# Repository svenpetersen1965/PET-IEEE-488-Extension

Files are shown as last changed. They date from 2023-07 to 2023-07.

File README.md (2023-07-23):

# PET-IEEE-488-Extension
This is a splitter and cable adapter for the Commodore PET IEEE-488 edge connector port. It can serve for connecting a "cheap" standard IEEE-488 cable with both sides IEEE-488 connectors to the edge connector IEEE-488 port of the PET. The original cables with an edge connector are a fortune nowadays.

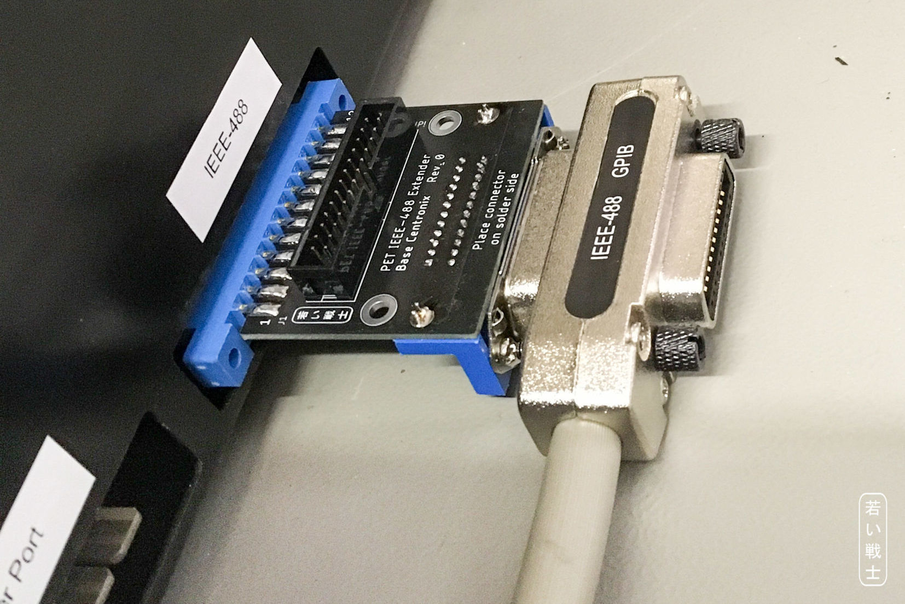
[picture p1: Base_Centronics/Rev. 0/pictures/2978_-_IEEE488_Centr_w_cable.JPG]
Centronics Base


Also, it can serve as a splitter for the SD2PET future. 

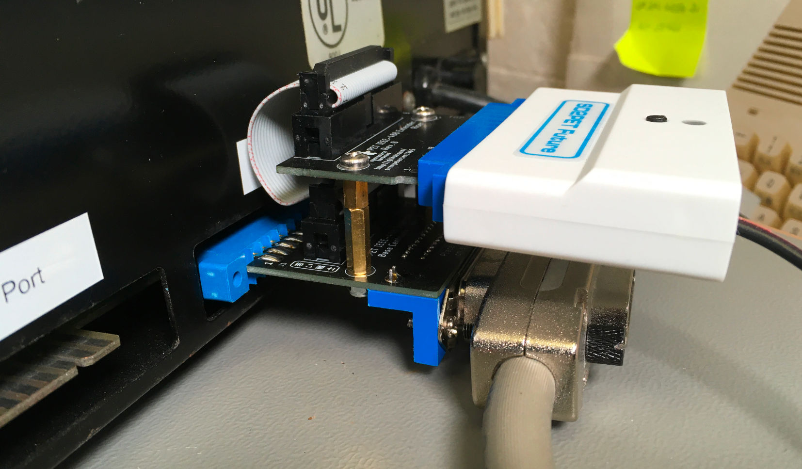
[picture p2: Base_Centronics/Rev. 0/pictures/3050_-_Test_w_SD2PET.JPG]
with Riser board and SD2PET future


There is a 3D printed case with label for the adapter. 

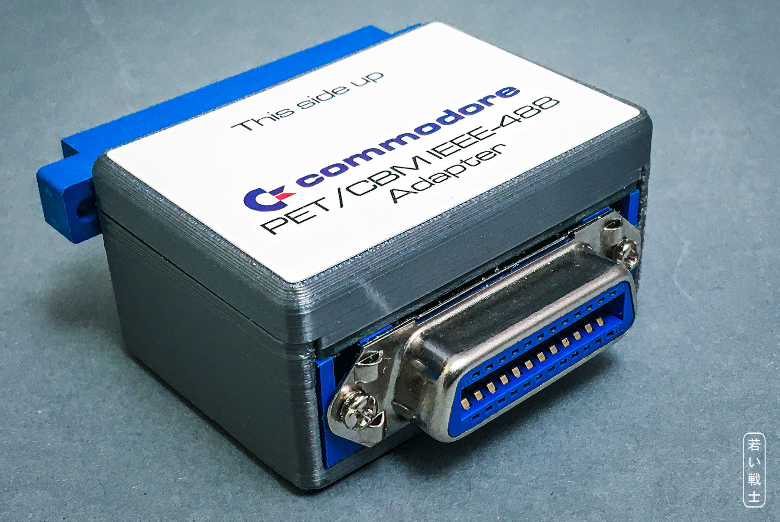
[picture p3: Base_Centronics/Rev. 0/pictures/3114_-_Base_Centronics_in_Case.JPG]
with Case


For splitting the bus, there is a riser card, which attaches to both, the normal and the centronics base board.

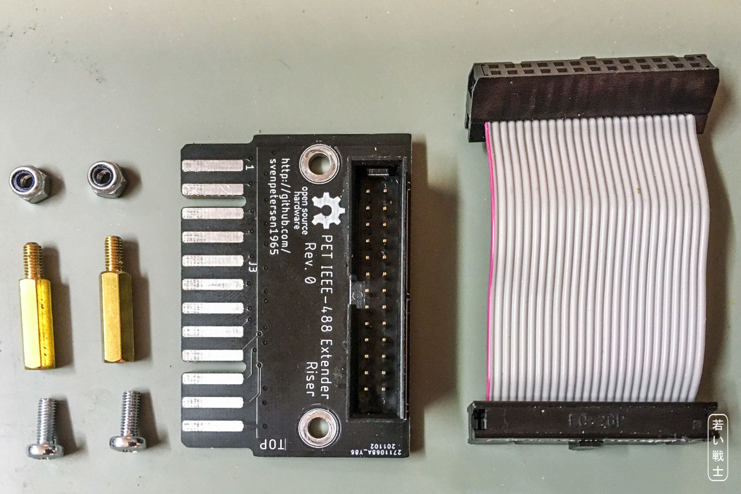
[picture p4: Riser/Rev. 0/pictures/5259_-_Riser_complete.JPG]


Here is a close up of the configuration with the riser card and the SD2PET.

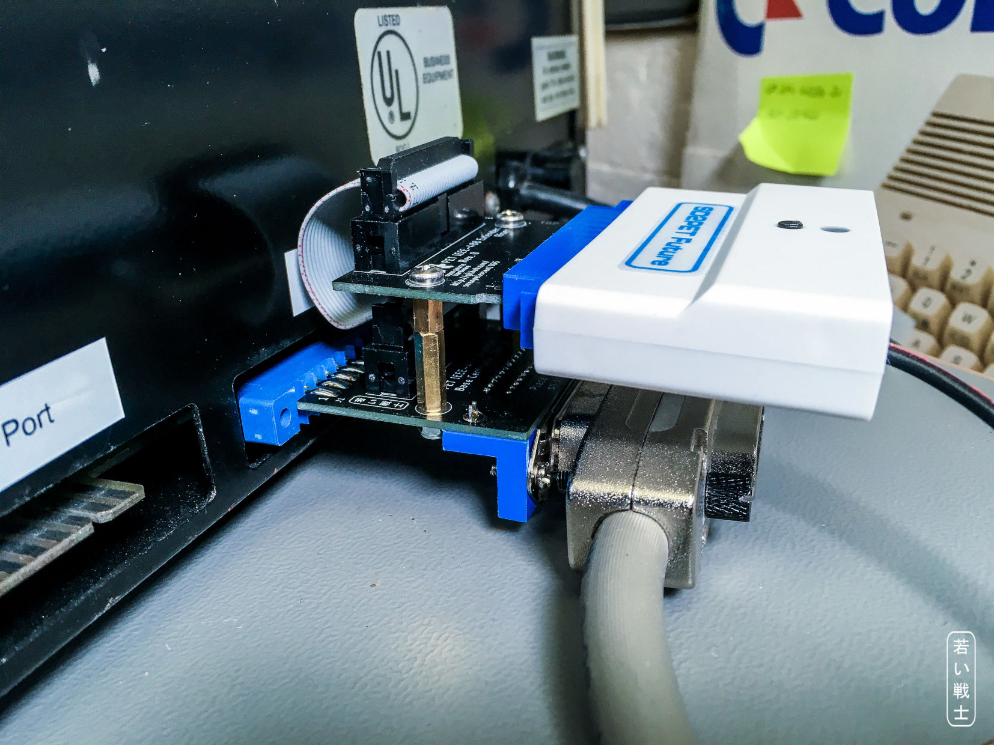
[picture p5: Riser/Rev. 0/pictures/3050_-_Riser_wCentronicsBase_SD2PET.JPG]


In this configuration, only the bottom part of the case is installed.

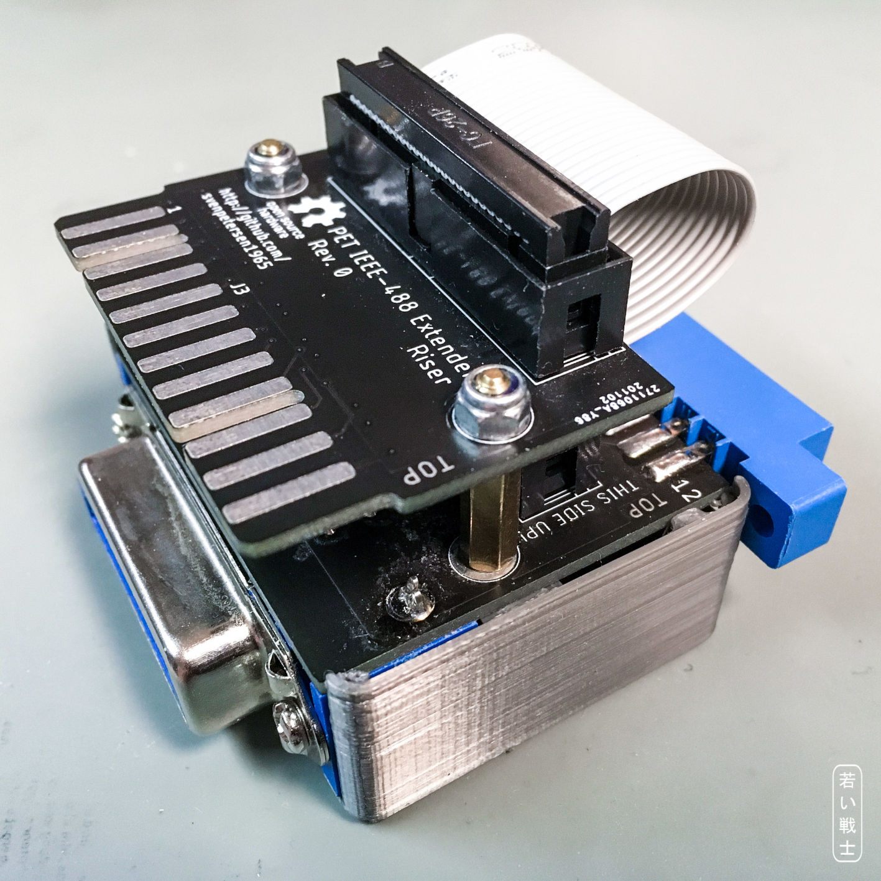
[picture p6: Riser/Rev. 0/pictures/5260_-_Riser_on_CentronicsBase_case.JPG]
with Case


This is the base board with an edge connector:

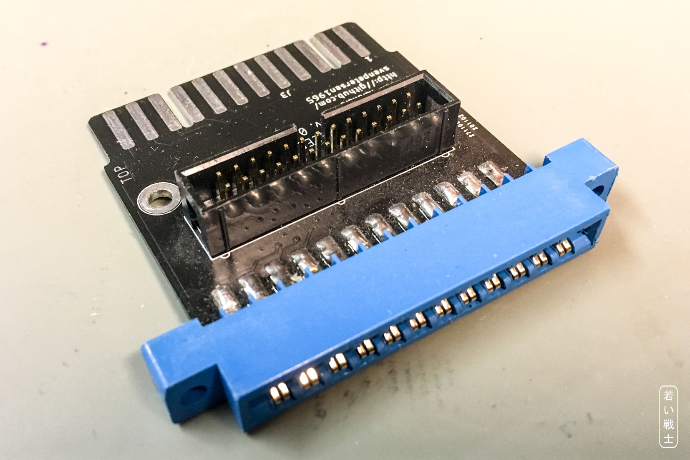
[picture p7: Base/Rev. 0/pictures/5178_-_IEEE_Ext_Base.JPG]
base with edge connector


Serving as an easy adapter for a DIY ribbon cable.

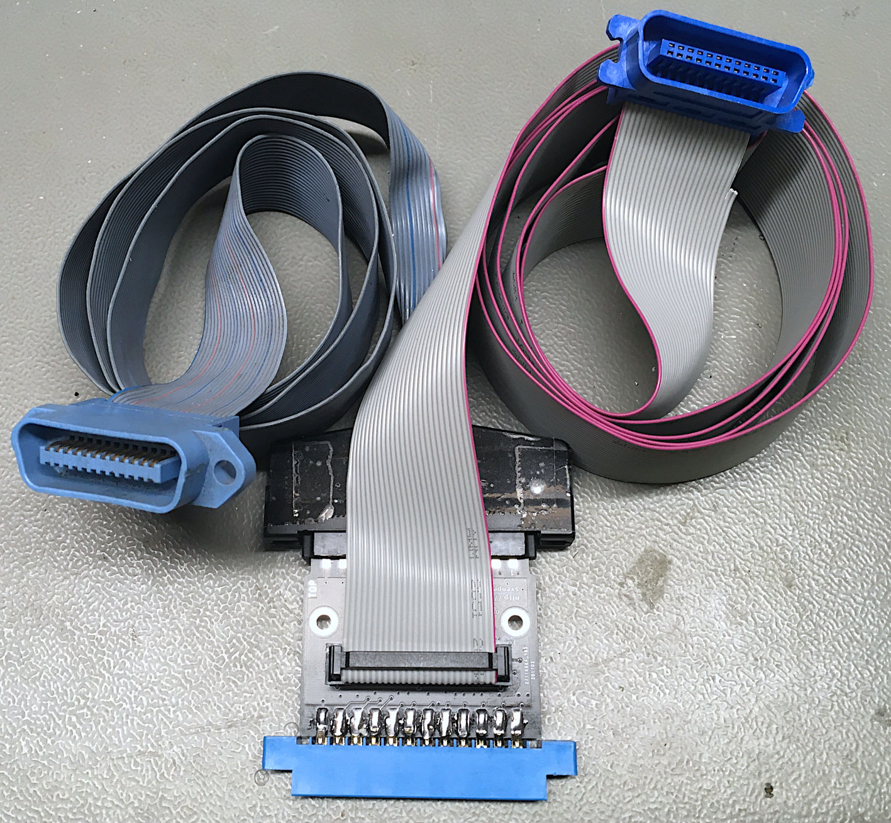
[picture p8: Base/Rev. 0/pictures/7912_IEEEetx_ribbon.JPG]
base with edge connector


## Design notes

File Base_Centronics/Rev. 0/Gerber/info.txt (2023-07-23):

      
       Board: IEEE_EXT_Base_Centr
       Rev.:  0
  
       Files:
       ======
  
       All Gerber files are generated in extended gerber format (RS274X)
       *.TOP        : Film top copper
       *.BOT        :  -"- bottom copper
       *.STC        :  -"- top soldermask 
       *.STS        :  -"- bottom soldermask
       *.PLC        :  -"- silk screen top
       *.PLS        :  -"- silk screen bottom
       *.DK         : Drills plated Through (Excellon)
       *.NDK        : Drills not plated Through (Excellon)
       *.OUT        : Board outline

       Board Size:
       ===========
       Length     :   54.0 mm
       Width      :   44.0 mm
       Thickness  :   1.6 mm
       Material   :   FR 4
       Copper     :   35 um
       Surface    :   HASL
       
       Remarks:
       ========
       Width >= 8mil
       Distance >= 6mil
       Drill >= 0.35mm

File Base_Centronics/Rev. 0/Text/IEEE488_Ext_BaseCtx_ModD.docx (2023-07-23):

Commodore PET IEEE-488 Extender Base Centronics Rev. 0

Module Description

The IEEE-488 extender can serve multiple purposes:

1. Splitting the card edge IEEE-488 connector via a riser board (Project No. 170), so an additional device like a SD2PET future can be connected.
2. Adapting an IEEE-488 cable to the edge connector of the PET.

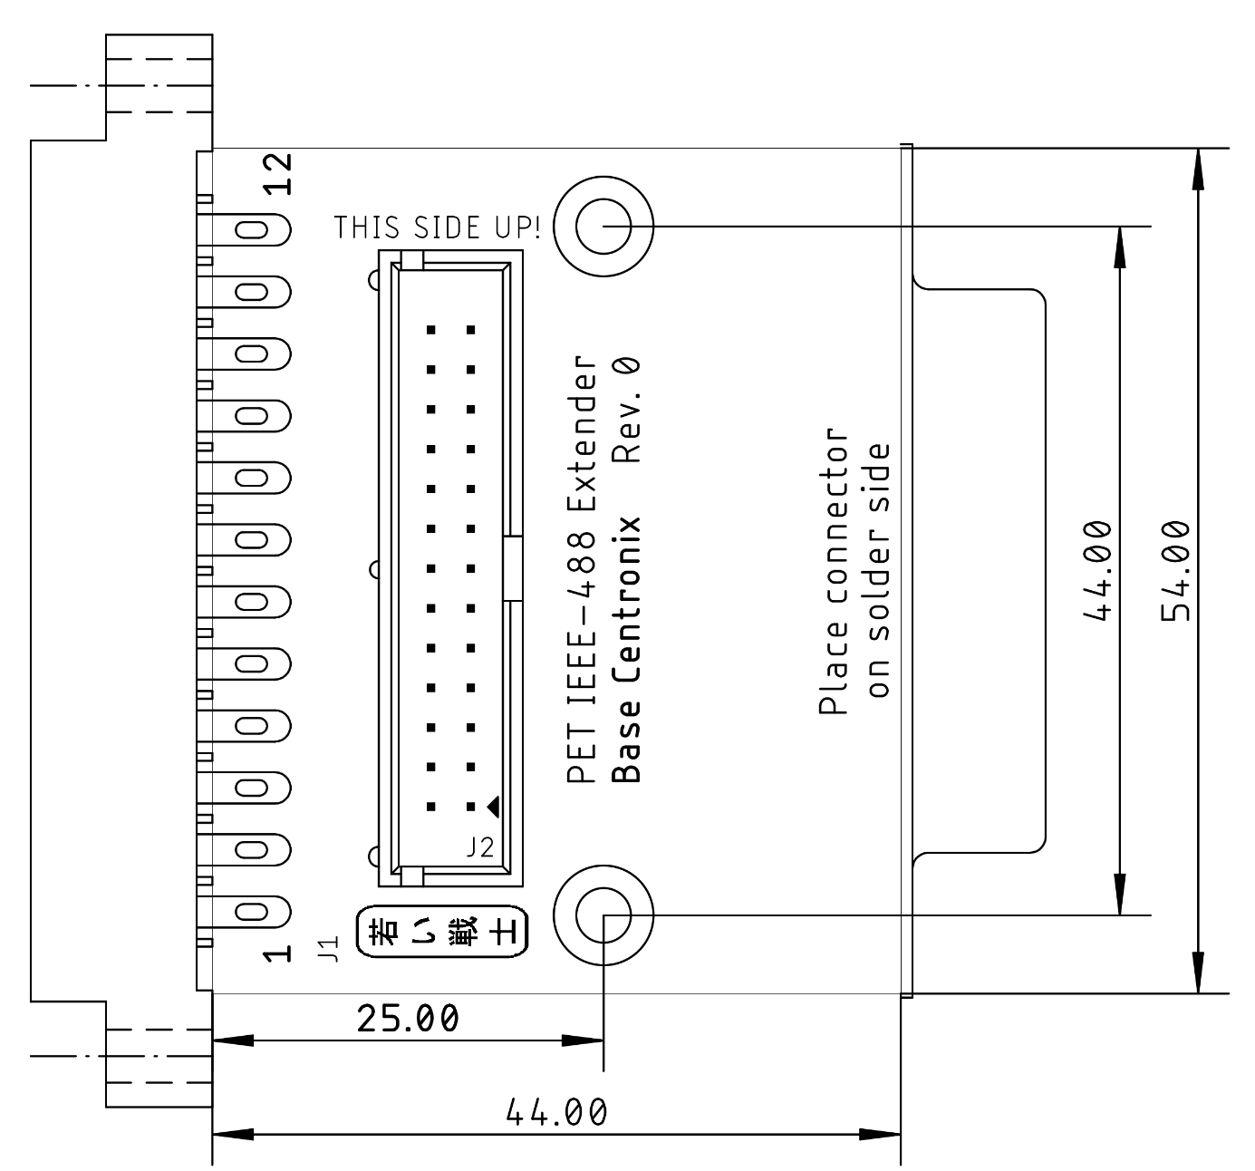
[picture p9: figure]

Figure 1: Dimensions of the IEEE-488 Extender

# 3D-Printed Case

Depending on the intended usage, there are different sorts of 3D cases/configurations. The 3D-printed case provides a good support for the extension board and the cable. If it is only intended to use the extension as an adapter for the Centronics type (=standard) IEEE-488 cables, the top shell can be installed (J2 cannot be assembled in this case). The height above the desktop of the PET is different than that of the Tynemouth Software/TFW8bit miniPET. The miniPET adapter case is 2mm higher.

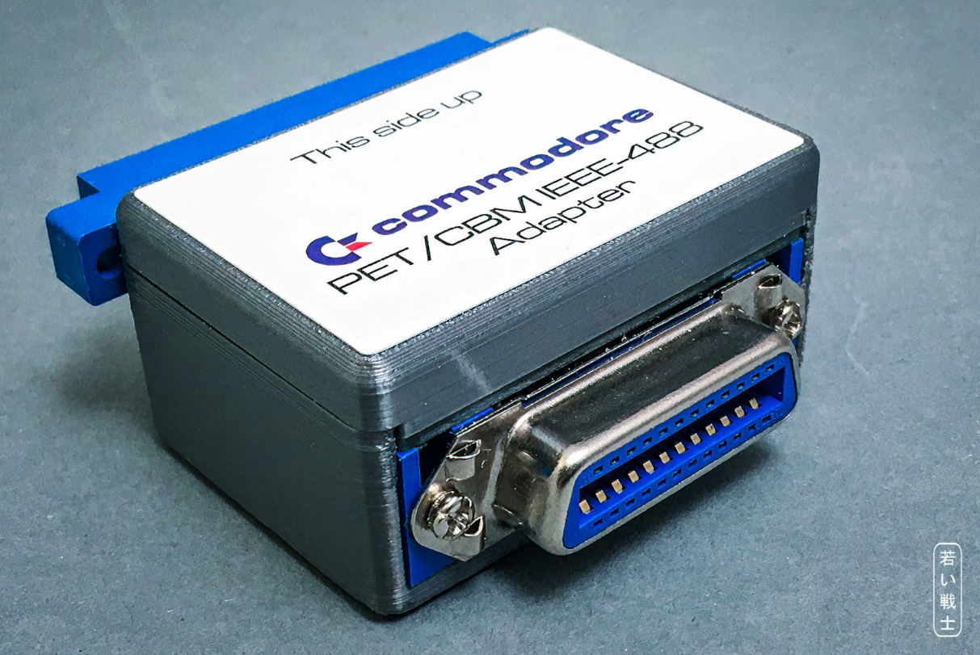
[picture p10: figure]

Figure 2: Full 3D printed case

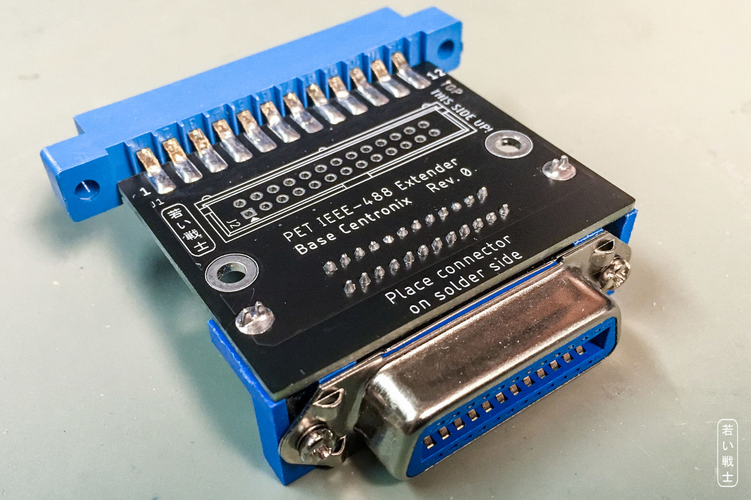
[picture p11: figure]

Figure 3: Centronics Base without J2

Figure 3 shows the Centronics Base without J2 to allow the top shell of the case to be installed.


Figure 4: Centronics Base with Riser and the bottom shell installed only

# Connectors

J1 is a female card edge connector, that connects to the PET/CBM Mainboard, J3 is a 24p. female Centronics connector (fits IEEE-488) (Ali Express “Series 57”), which connects to the IEEE-488 peripherals via an IEEE-488 cable. J2 is a 2x13 pin header/box connector.

J1 | J3 | Signal | J2 | J2 | Signal | J3 | J1
1 | 1 | DIO1 | 1 | 2 | DIO5 | 13 | A
2 | 2 | DIO2 | 3 | 4 | DIO6 | 14 | B
3 | 3 | DIO3 | 5 | 6 | DIO7 | 15 | C
4 | 4 | DIO4 | 7 | 8 | DIO8 | 16 | D
5 | 5 | EOI | 9 | 10 | REN | 17 | E
6 | 6 | DAV | 11 | 12 | GND | 18 | F
7 | 7 | NRFD | 13 | 14 | GND | 19 | H
8 | 8 | NDAC | 15 | 16 | GND | 20 | J
9 | 9 | IFC | 17 | 18 | GND | 21 | K
10 | 10 | SRQ | 19 | 20 | GND | 22 | L
11 | 11 | ATN | 21 | 22 | GND | 23 | M
12 | 12 | GND | 23 | 24 | GND | 24 | N
- | - | GND | 25 | 26 | GND | - | -

Table 1: IEEE-488 signal pinouts

The shield of J3 is connected to GND.

# SD2PET future Splitter

The SD2PET future has an edge connector IEEE-488 interface, which does not allow to connect any other IEEE-488 peripheral. It might be desired to do so, though. In this case, the SD2PET future has to drive both, the PET and the peripheral bus load. The maximum load is not defined.

The configuration was tested with a CBM8032 and a CBM8050 floppy disk drive attached via a 1.5 meter long IEEE-488 cable. The CBM8050 has to be set (via hardware) to a device address other than 8, since this is the default address of the SD2PET future. It is not possible to switch off the CBM8050 and reconfigure the device address of the SD2PET.

Using the SD2PET future and a printer was not tested, but very likely works, since the interface circuitry is similar to the CBM8050.

The bus splitting requires the riser board, like shown in Figure 4.

# Revision History

## Rev. 0

- Prototype (fully functional)

IEEE488_Ext_BaseCtx_ModD.docx 23.07.2023 17:27 Drafted by Sven Petersen Page 2 of 2 Doc.-No.: 204-6-01-00

IEEE488_Ext_BaseCtx_ModD.docx 23.07.2023 17:27 Drafted by Sven Petersen Page 1 of 1 Doc.-No.: 000-6-00-00

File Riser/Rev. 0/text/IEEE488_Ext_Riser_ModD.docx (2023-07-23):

Commodore PET IEEE-488 Extender – Riser Board Rev. 0

Module Description

# Introduction

The IEEE-488 extender riser board is connected to either the base board with edge connector (Project 169) or the base board with Centronics connector (24p. = IEEE-488 connector, Project. No. 204). It serves for connecting IEEE cables with and edge connector or a peripheral like the SD2PET, which has an edge connector installed.

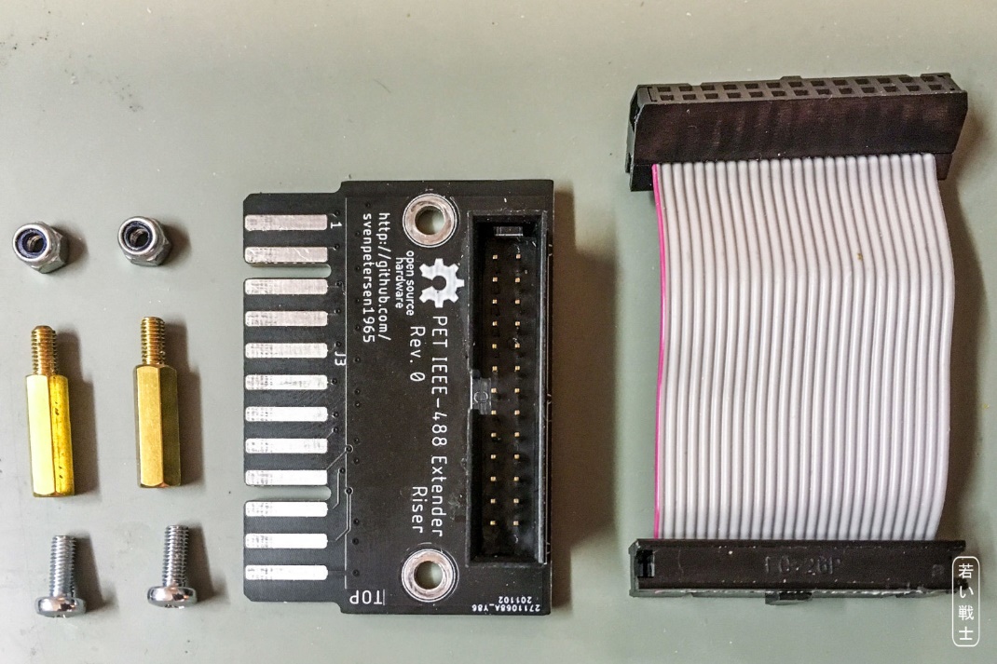
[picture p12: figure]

Figure 1: Riser Board with jumper cable and mounting material

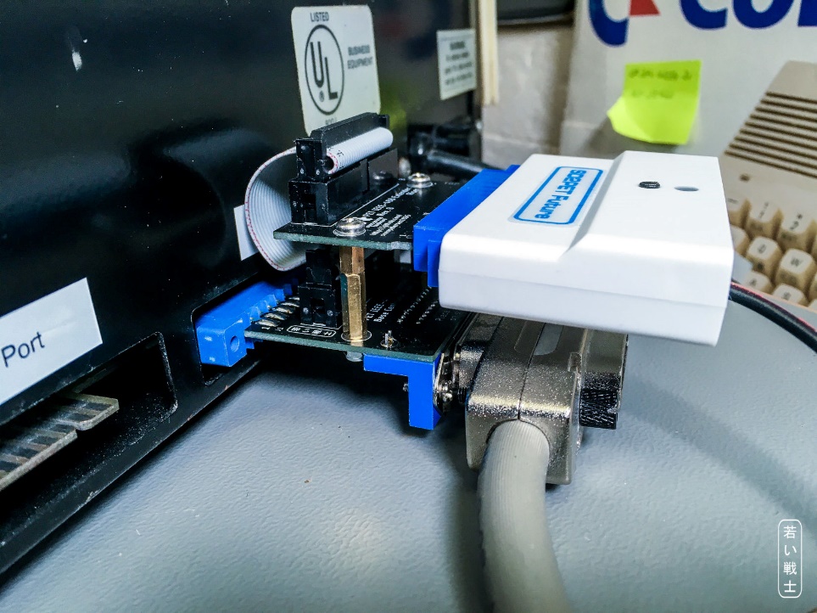
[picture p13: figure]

Figure 2: Riser Board on a Centronics Base Board with an SD2PET

# Dimensions

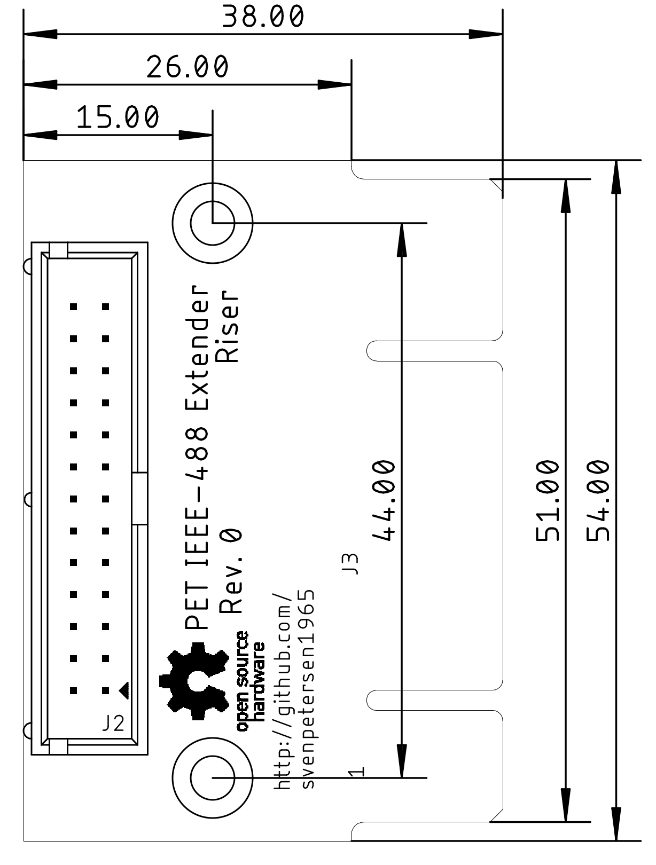
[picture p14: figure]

Figure 3: Dimensions of the IEEE-488 Extender

# Connectors

J3/top | Signal | J2 | J2 | Signal | J3/bottom
1 | DIO1 | 1 | 2 | DIO5 | A
2 | DIO2 | 3 | 4 | DIO6 | B
3 | DIO3 | 5 | 6 | DIO7 | C
4 | DIO4 | 7 | 8 | DIO8 | D
5 | EOI | 9 | 10 | REN | E
6 | DAV | 11 | 12 | GND | F
7 | NRFD | 13 | 14 | GND | H
8 | NDAC | 15 | 16 | GND | J
9 | IFC | 17 | 18 | GND | K
10 | SRQ | 19 | 20 | GND | L
11 | ATN | 21 | 22 | GND | M
12 | GND | 23 | 24 | GND | N
- | GND | 25 | 26 | GND | -

Table 1: IEEE-488 signal pinouts

J3 is a card edge structure on the PCB, which connects to the IEEE-488 peripherals via the PET-IEEE-488 cable or directly (in case of the SD2PET future). J2 is a 2x13 pin header/box connector for the jumper cable to the respective base board.

# Cable

The jumper ribbon cable connects J2 or the Riser Board to J2 of the desired base board. Since this cable is usually installed only once, there is no need for a strain relief. This way, the standoff between riser board and the base board can be 15mm only.

# 3D-Printed Case

The bottom Shell of the Case for the Centronics Base can be used to support the board stack.


Figure 4: Board stack with Centronics Base and the bottom shell of the Centronics case

The recommended mounting material:

- 2x 15mm standoffs
- 2x M3x8 Screws (e.g. DIN 7985, Philips dead)
- 2x Nut M3 self-locking (DIN 985)

# Application Note

When using it as a splitter for the SD2PET, it is not tested to drive more than the SD2PET and one more peripheral. It is suspected, that the SD2PET is not capable to drive bussed with several devices.

# Revision History

## Rev. 0

- Prototype (fully functional)

IEEE488_Ext_Riser_ModD.docx 18.06.2023 22:15 Drafted by Sven Petersen Page 2 of 2 Doc.-No.: 170-6-01-00

IEEE488_Ext_Riser_ModD.docx 18.06.2023 22:15 Drafted by Sven Petersen Page 1 of 1 Doc.-No.: 000-6-00-00

ENZIANWEG 16 ● 83052 BRUCKMÜHL TEL (08062) 728704 ● FAX (08062) 728705

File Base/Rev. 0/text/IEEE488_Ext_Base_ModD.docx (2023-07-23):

Commodore PET IEEE-488 Extender Base Board Rev. 0

Module Description

The IEEE-488 extender can serve multiple purposes:

1. Splitting the card edge IEEE-488 connector, so an additional device other than a SD2PET future can be connected.
2. Connecting a cheap DIY ribbon IEEE-488 cable. It is recommended to keep this ribbon cable as short as possible

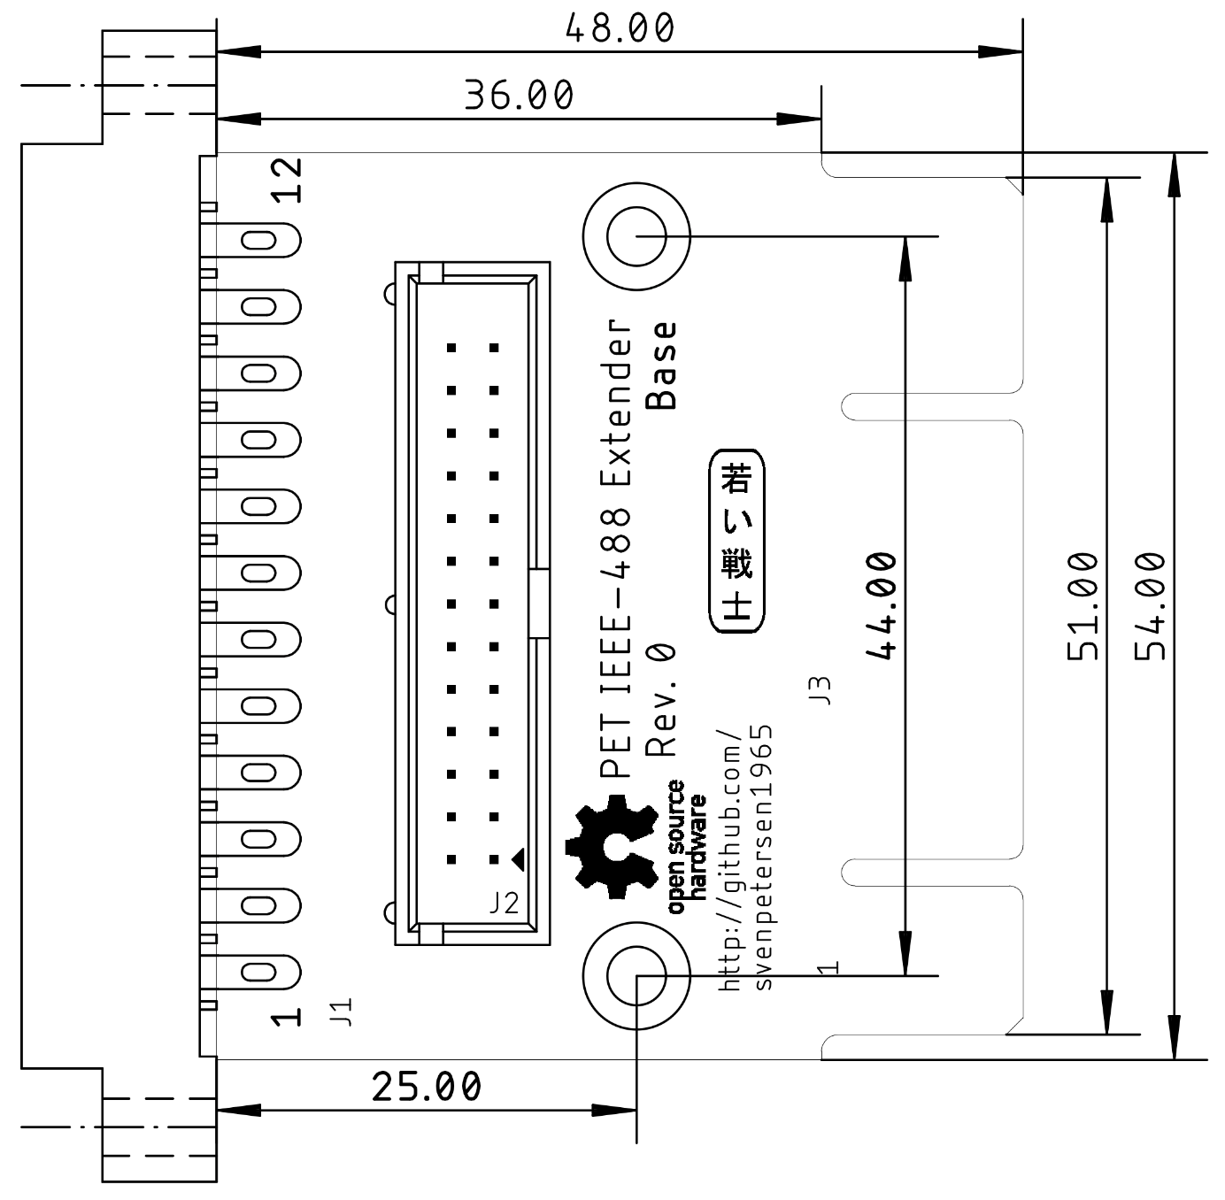
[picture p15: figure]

Figure 1: Dimensions of the IEEE-488 Extender

# Connectors

J1 is a female card edge connector, that connects to the PET/CBM Mainboard, J3 is a card edge structure on the PCB, which connects to the IEEE-488 peripherals via the PET-IEEE-488 cable or directly (in case of the SD2PET future). J2 is a 2x13 pin header/box connector.

J1, J3/top | Signal | J2 | J2 | Signal | J1, J3/bottom
1 | DIO1 | 1 | 2 | DIO5 | A
2 | DIO2 | 3 | 4 | DIO6 | B
3 | DIO3 | 5 | 6 | DIO7 | C
4 | DIO4 | 7 | 8 | DIO8 | D
5 | EOI | 9 | 10 | REN | E
6 | DAV | 11 | 12 | GND | F
7 | NRFD | 13 | 14 | GND | H
8 | NDAC | 15 | 16 | GND | J
9 | IFC | 17 | 18 | GND | K
10 | SRQ | 19 | 20 | GND | L
11 | ATN | 21 | 22 | GND | M
12 | GND | 23 | 24 | GND | N
- | GND | 25 | 26 | GND | -

Table 1: IEEE-488 signal pinouts

# Pictures

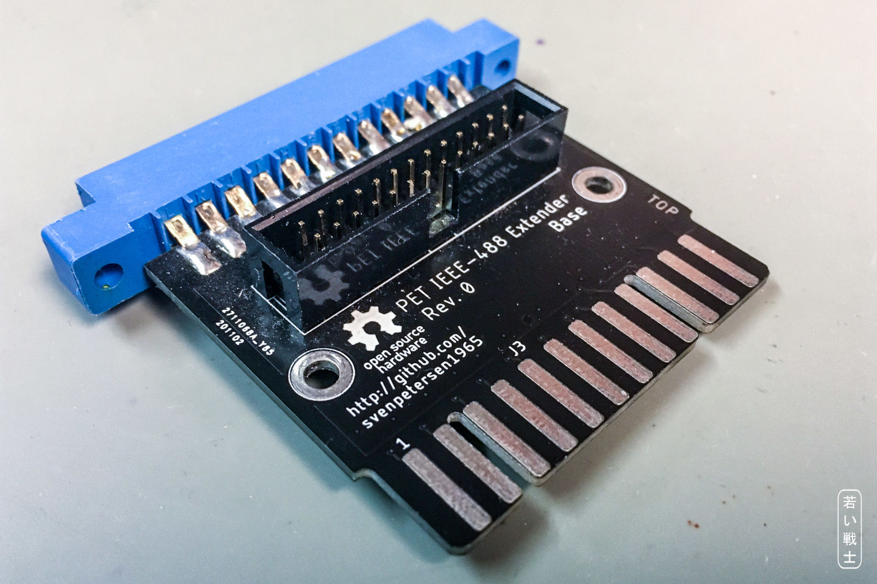
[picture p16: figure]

Figure 2: IEEE-488 Extender Base Board

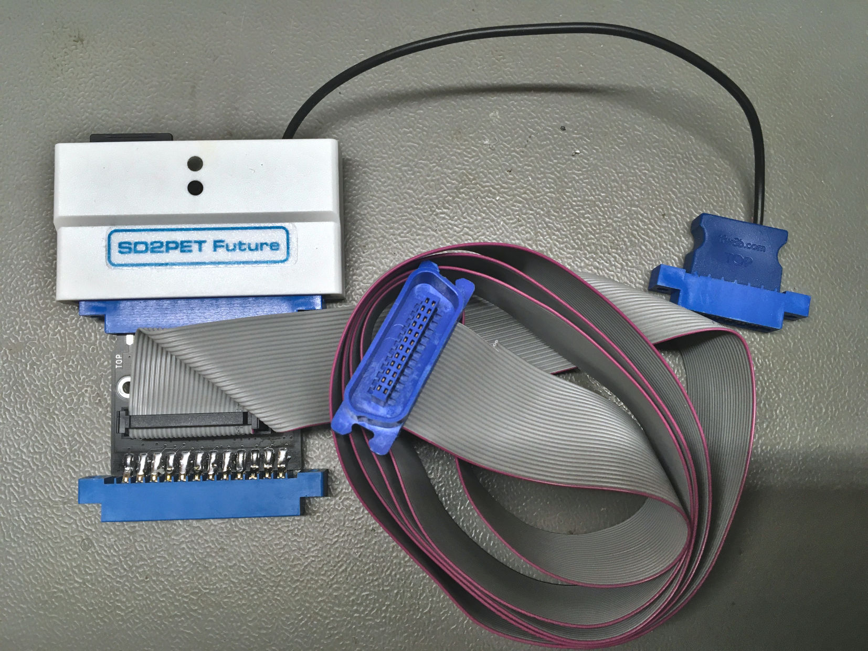
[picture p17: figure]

Figure 3: Base Board with SD2PET Future and a ribbon cable

# Revision History

## Rev. 0

- Prototype (fully functional)

IEEE488_Ext_Base_ModD.docx 23.07.2023 15:42 Drafted by Sven Petersen Page 2 of 2 Doc.-No.: 169-6-01-00

IEEE488_Ext_Base_ModD.docx 23.07.2023 15:42 Drafted by Sven Petersen Page 1 of 1 Doc.-No.: 000-6-00-00

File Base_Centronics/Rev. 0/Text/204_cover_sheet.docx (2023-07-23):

Project Documentation

Commodore IEEE-488 Extender

Base Centronics

Project number: 204

Revision: 0

Date: 18.11.2022

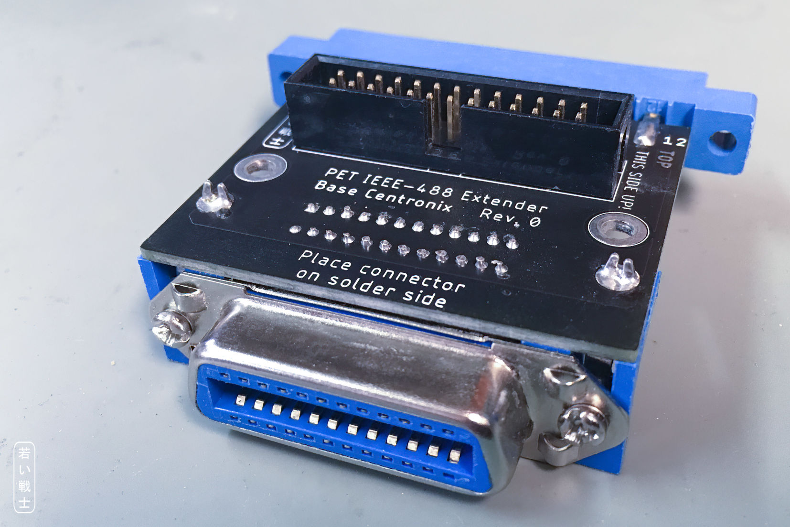
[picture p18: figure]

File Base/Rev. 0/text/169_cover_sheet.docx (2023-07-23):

Project Documentation

Commodore IEEE-488 Extender Base

Project number: 169

Revision: 0

Date: 03.09.2022


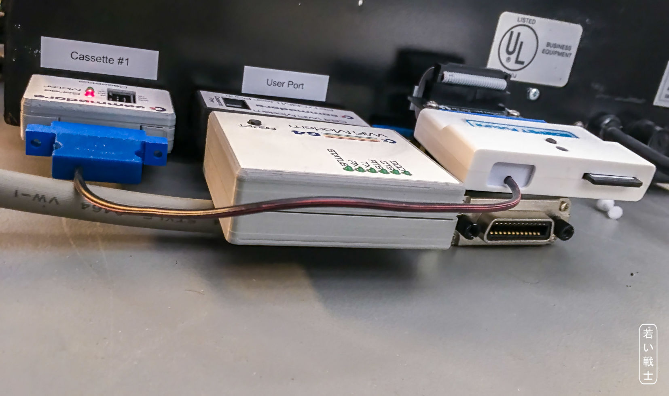
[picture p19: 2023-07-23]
Base_Centronics/Rev. 0/pictures/2981_-_IEEE488_Centr_fit_cbl_SD2PET.JPG

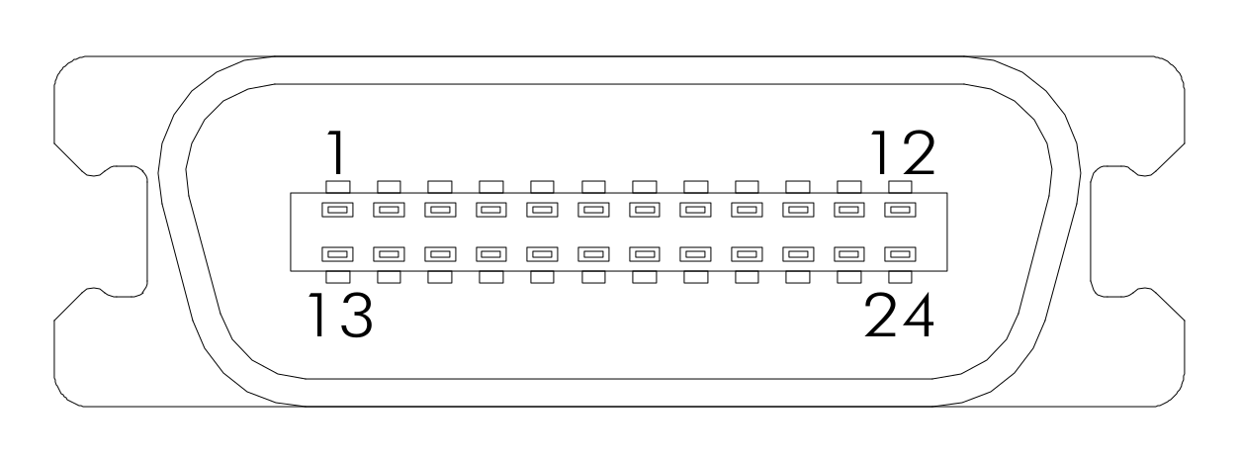
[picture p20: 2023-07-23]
Cable/Rev. 0/Pictures/GPIB.png

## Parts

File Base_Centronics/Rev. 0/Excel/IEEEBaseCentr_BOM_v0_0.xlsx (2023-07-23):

Commodore PET IEEE-488 Extender Base Board Centronics Rev. 0
Bill of Material Rev. 0.0
Pos. | Qty | Value | Footprint | Ref.-No. | Comment
1 | 1 | 204-2-01-00 | 2 Layer | PCB Rev. 0 | 2 layer, Cu 35µ, HASL, 44.0mm x 54.0mm, 1.6mm FR4
2 | 1 | 2x13 box pin header, 2.54mm | 2X13WV | J2 | e.g. Reichelt.de WSL26G
3 | 1 | 2x12 edge connector 3.96mm pitch | USERPORT | J1 | edge connector, C64 user port, Ali Express: "Series 805"
4 | 1 | 24p Centronics, 90°, female | PET_IEEE_CENTRONICS | J3 | PCB mount 24 pin Centronics, female, 90°. Ali Express "Series 57", https://a.aliexpress.com/_mr8TkVY

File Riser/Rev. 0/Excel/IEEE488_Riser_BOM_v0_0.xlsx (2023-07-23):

PET IEEE-488 Extender - Riser Board Rev. 0
Bill of Material Rev. 0.0
Pos. | Qty | Value | Footprint | Ref.-No. | Comment
1 | 1 | 170-2-01-00 | 2 Layer | PCB Rev. 0 | 2 layer, Cu 35µ, HASL, 38.0mm x 54.0mm, 1.6mm FR4
 | 1 | Box pin header, 2x13p, 2.54mm | 2X13WV | J2 | e.g. Reichelt.de WSL 26G
 | 2 | IDC receptacle, 2x13p, 2.54mm |  | Cable (Drawing 169-2-03-00) | e.g. Reichelt.de PFL 26 (do not install strain relief)
 | 60mm | AWG28, 26p, pitch 1.27mm |  | Cable (Drawing 169-2-03-00) | ribbon cable e.g. Reichelt.de AWG 28-26G 3M (3 meters)
 | 2 | standoff M3/15mm (male +female)
 | 2 | locking nuts M3 |  |  | DIN985, zinc plated
 | 2 | Screws, M3x8 |  |  | DIN7985, philips head, zinc plated

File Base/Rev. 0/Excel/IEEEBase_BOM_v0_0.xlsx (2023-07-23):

Commodore PET IEEE-488 Extender Base Board Rev. 0
Bill of Material Rev. 0.0
Pos. | Qty | Value | Footprint | Ref.-No. | Comment
1 | 1 | 169-2-01-00 | 2 Layer | PCB Rev. 0 | 2 layer, Cu 35µ, HASL, 48.0mm x 54.0mm, 1.6mm FR4
 | 1 | 2x13 box pin header, 2.54mm | 2X13WV | J2 | e.g. Reichelt.de WSL26G
 | 1 | 2x12 edge connector 3.96mm pitch | USERPORT | J1 | edge connector, C64 user port, Ali Express: "Series 805"

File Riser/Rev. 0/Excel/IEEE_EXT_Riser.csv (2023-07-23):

Qty | Value | Device | Package | Parts | Description
1 |  | 2X13WANNE | 2X13WV | J2
2 |  | BOHR3,5 | BOHR3,5 | DRL1, DRL2
1 | OPEN_SOURCE_HW | OPEN_SOURCE_HW | OPENHW | U$9
1 | PET_IEEE_M | PET_IEEE_M | PET_IEEE_M | J3

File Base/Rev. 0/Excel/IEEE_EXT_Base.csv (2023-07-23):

Qty | Value | Device | Package | Parts | Description
1 |  | 2X13WANNE | 2X13WV | J2
2 |  | BOHR3,5 | BOHR3,5 | DRL1, DRL2
1 | OPEN_SOURCE_HW | OPEN_SOURCE_HW | OPENHW | U$9
1 | PET_IEEE | PET_IEEE | USERPORT | J1
1 | PET_IEEE_M | PET_IEEE_M | PET_IEEE_M | J3

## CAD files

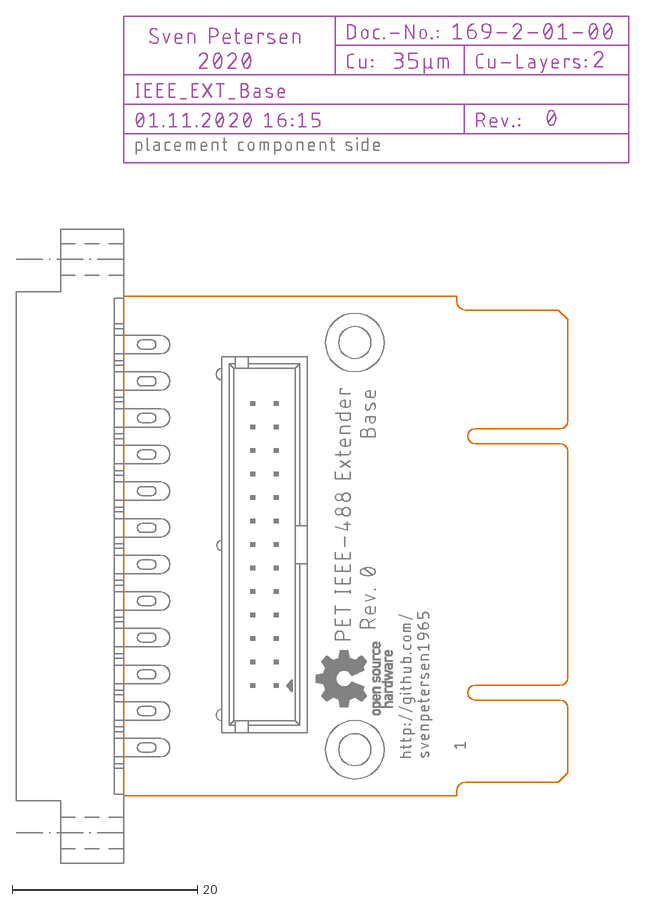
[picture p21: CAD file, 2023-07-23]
Base/Rev. 0/dxf/IEEE_EXT_Base.dxf
66.2 x 91.5

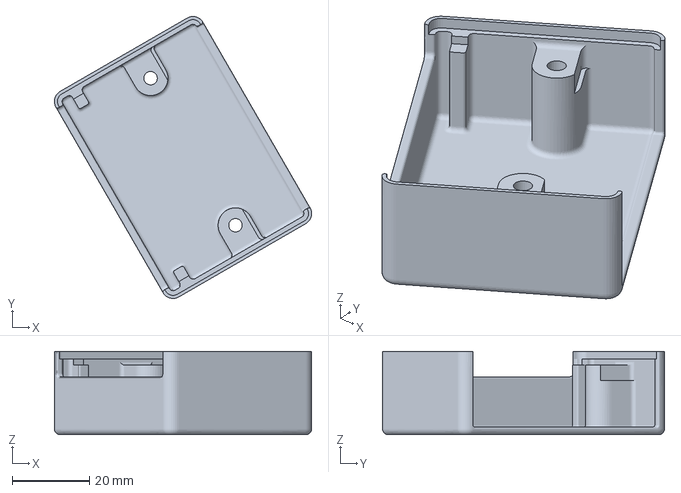
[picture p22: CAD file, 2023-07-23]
Base_Centronics/case/Rev.0/gcode/Bottom shell miniPET.3mf
66.7 x 73.1 x 21.6 mm

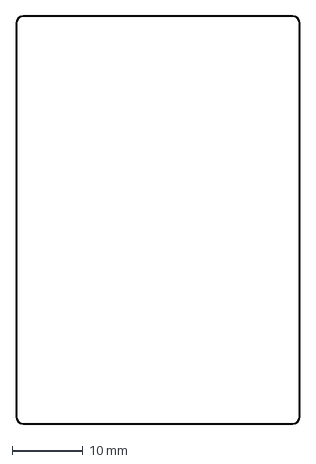
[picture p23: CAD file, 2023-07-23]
Base_Centronics/case/Rev.0/label/label_outline.dxf
40.0 x 57.5 mm

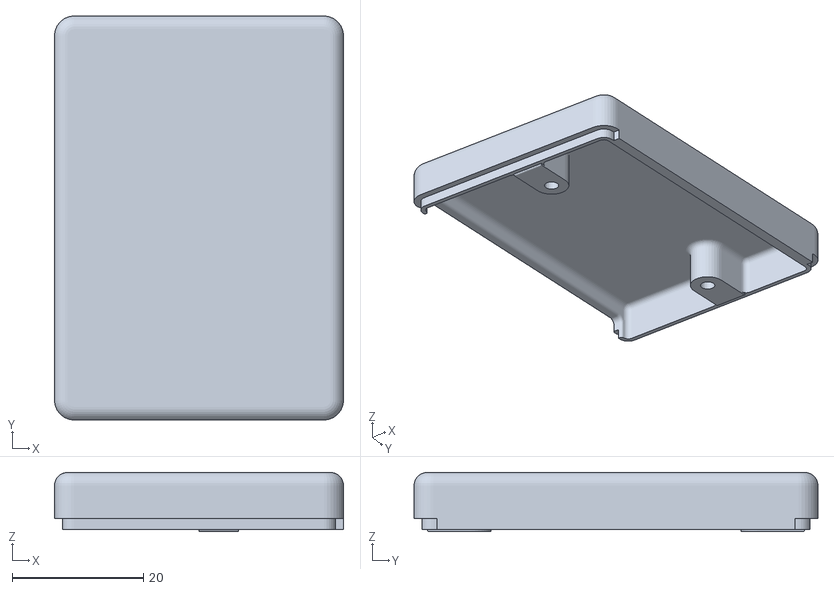
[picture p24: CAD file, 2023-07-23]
Base_Centronics/case/Rev.0/stl/IEEE_centr_Top_shell.stl
44.0 x 61.5 x 9.00

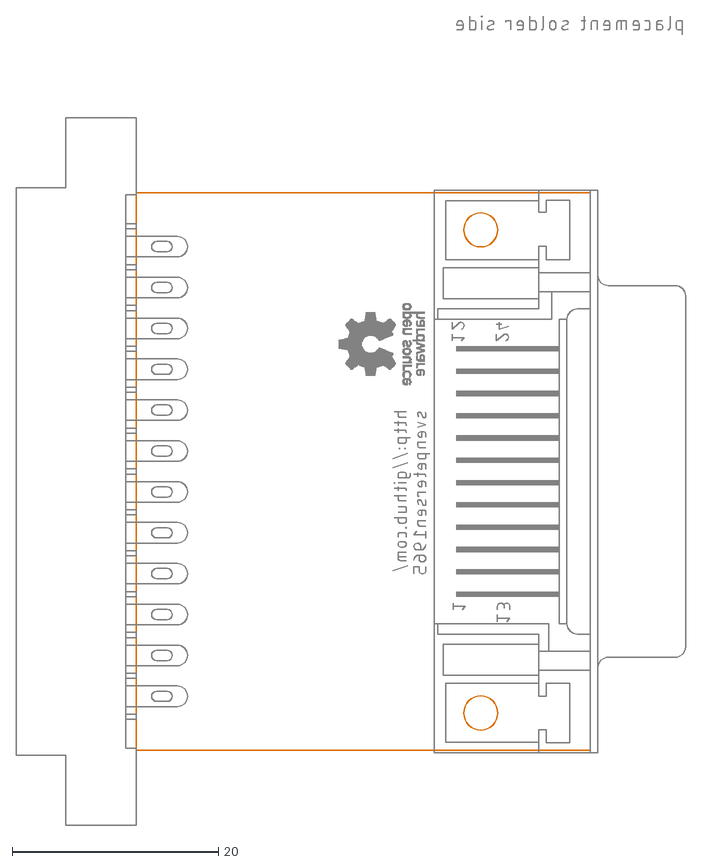
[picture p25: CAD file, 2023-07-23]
Base_Centronics/Rev. 0/dxf/IEEE_EXT_Base_Centr_bottom.dxf
64.8 x 78.4

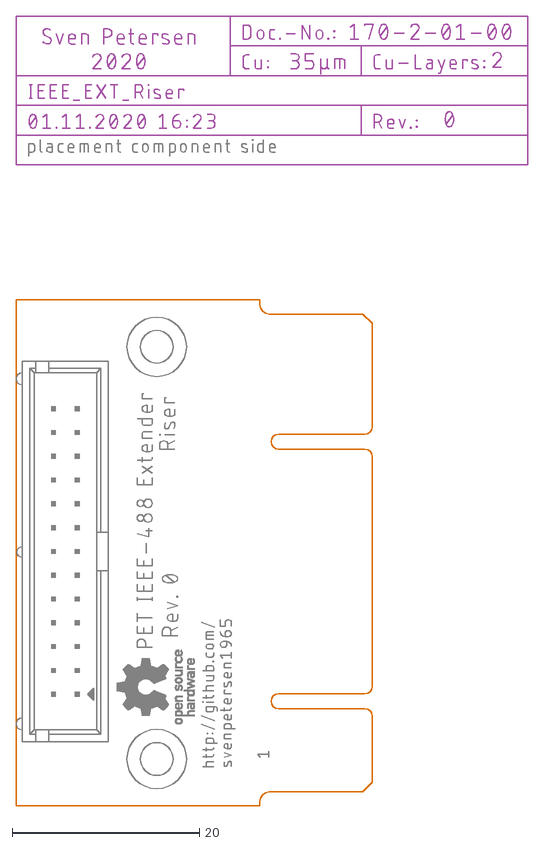
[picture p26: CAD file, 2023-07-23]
Riser/Rev. 0/dxf/IEEE_EXT_Riser.dxf
54.6 x 84.3

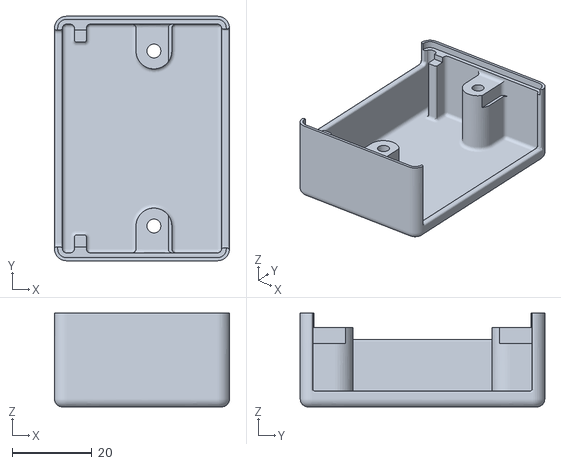
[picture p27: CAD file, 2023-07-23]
Base_Centronics/case/Rev.0/stl/IEEE_centr_Bottom shell.stl
44.0 x 61.5 x 23.6

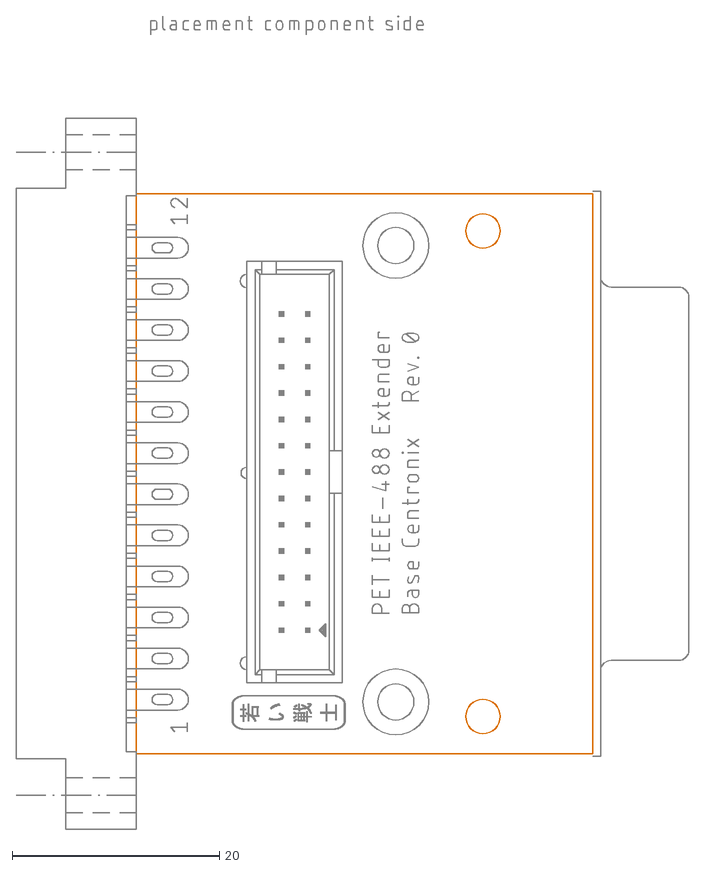
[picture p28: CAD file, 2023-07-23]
Base_Centronics/Rev. 0/dxf/IEEE_EXT_Base_Centr_top.dxf
64.8 x 78.4

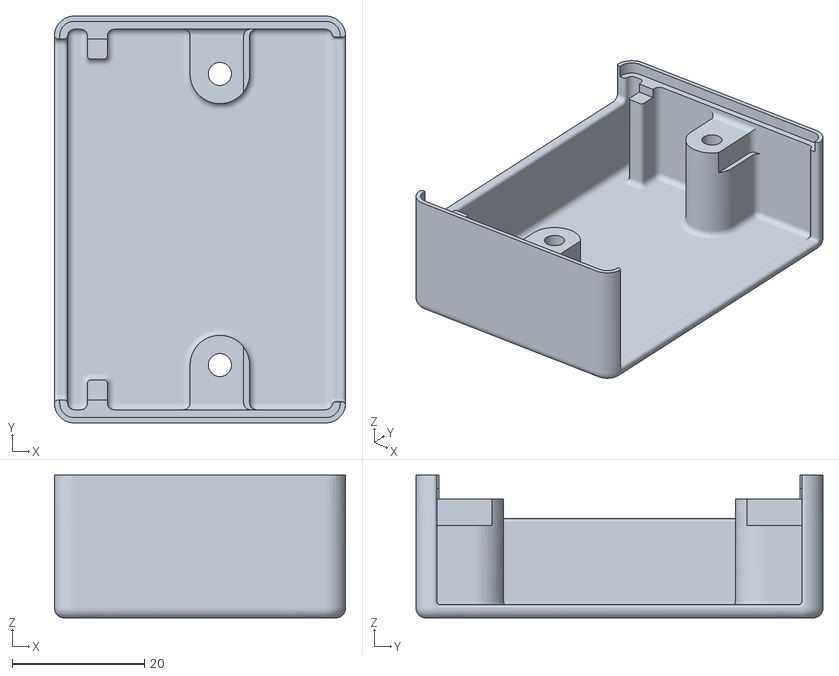
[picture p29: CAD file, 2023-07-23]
Base_Centronics/case/Rev.0/stl/Bottom shell miniPET.stl
44.0 x 61.5 x 21.6

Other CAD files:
Base_Centronics/case/Rev.0/Fusion 360/IEEE_Base_Centronics_case v12.f3d
Base_Centronics/case/Rev.0/Fusion 360/IEEE_Base_Centronics_case_miniPET v3.f3d

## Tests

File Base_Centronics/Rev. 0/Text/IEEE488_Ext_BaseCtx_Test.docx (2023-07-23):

Commodore PET IEEE-488 Extender Base Centronics Rev. 0

Testing

# Setup

- CBM3016 computer
- CBM8032 computer
- CBM8050 floppy disk drive
- TFW8bit.com SD2PET future
- Standard Centronics IEEE-488 cable (1.5m)
- Centronics Base Rev. 0 with case
- Centronics Base Rev. 0 with Riser and jumper cable cable (drawing no. 169-3-02-00)

# Test execution

The Centronics Base was installed in the PET’s IEEE-488 port and a cable was attached.


Figure 1: Installed Centronics Base with cable

The cable could be installed and was sitting firmly enough. There are no known screw posts for the connector (J3) to fit with the screws of the cable.

Then, a CBM8050 floppy disk drive was connected. Both, the computer and the drive were switched on. The drive can be flawlessly accessed.

A test fit was performed with SD2PET future, the CBM8050 (device address 9) with cable and a user port WiFi modem (Figure 3). The configuration did not interfere mechanically. The SD2PET future could be accessed as could the CBM8050. It was possible to copy the content of several floppy disks to the SD2PET future without any problems.

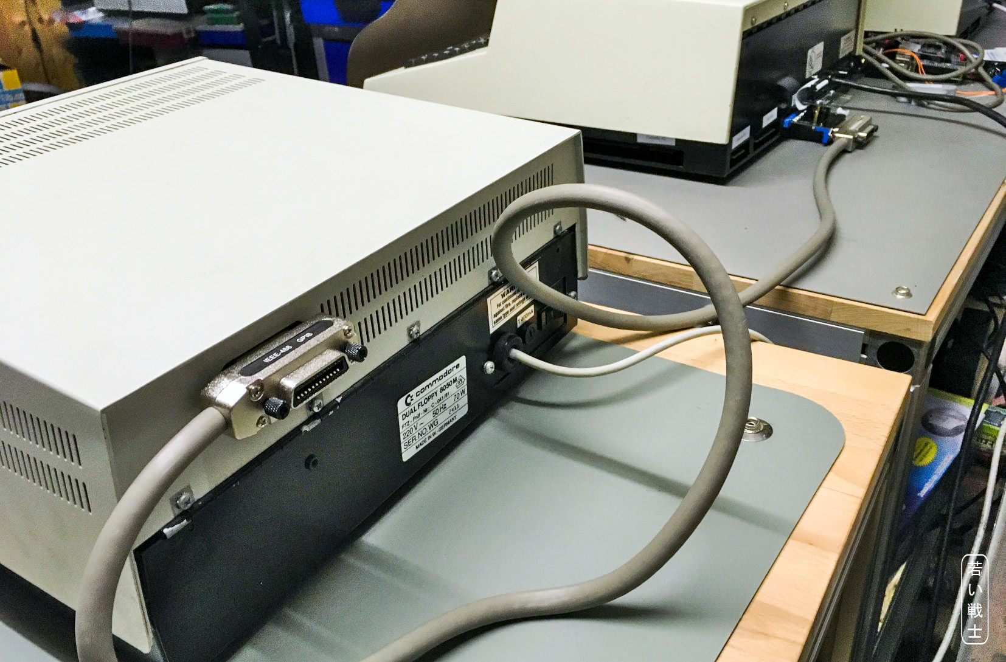
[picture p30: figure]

Figure 2: CBM8050 drive connected via cable and the Centronics Base rev. 0

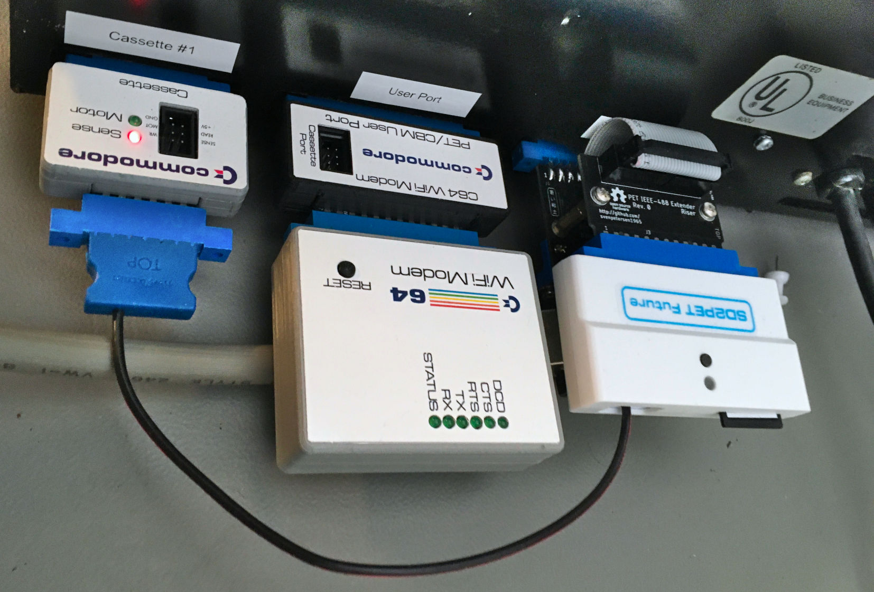
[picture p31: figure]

Figure 3: Centronics Base with Riser card, SD2PET future and user port peripherals (Wifi modem)

# Other Computers

The tests were repeated with the CBM3016 and the miniPET. No problems were noticed.

# Conclusion

The Centronics Base rev. 0 is working flawlessly.

IEEE488_Ext_BaseCtx_ModD.docx 23.07.2023 17:11 Drafted by Sven Petersen Page 2 of 2 Doc.-No.: 204-6-02-00

IEEE488_Ext_BaseCtx_ModD.docx 23.07.2023 17:11 Drafted by Sven Petersen Page 1 of 1 Doc.-No.: 000-6-00-00

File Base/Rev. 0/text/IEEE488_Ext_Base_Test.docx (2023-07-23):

Commodore PET IEEE-488 Extender Base Board Rev. 0

Testing

# Setup

The tests were conducted with a CBM8032 computer, a CBM8050 Floppy Disk Drive, an SD2PET future and a DIY ribbon cable (appr. 1 meter long). Further, a C64 with an IEEE-488 interface was used

# Test Execution

## Direct SD2PET

The SD2PET future was connected to the Base Board, which was then connected to the IEEE-488 port of the CBM8032.

The SD2PET could be accessed without a problem.

## CBM8050 via ribbon cable

The CBM8050 was connected via the base board and the ribbon cable. The 8050 could be accessed.

## CBM8050 via ribbon cable to IEEE488 interface and a C64

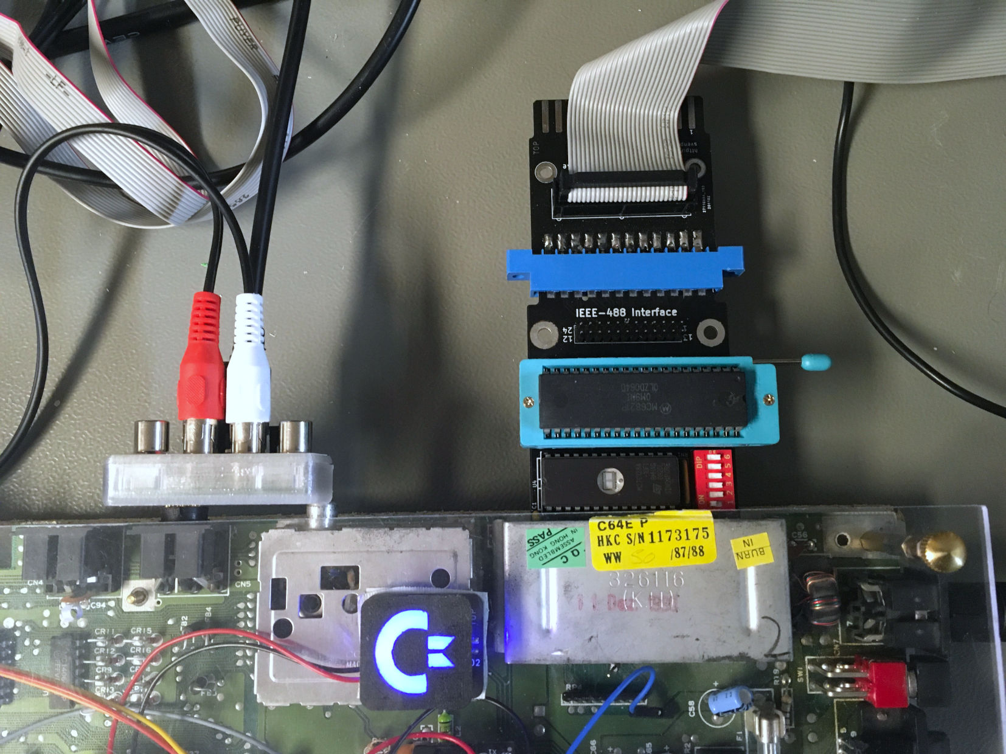
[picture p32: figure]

Figure 1: Test with C64 an IEEE-488 interface and a CBM8050

The CBM8050 could be accessed via the shown configuration. The result was not perfect, though. It is not determined, if this is matter of the interface or the ribbon cable.

# Conclusion

The PET IEEE-488 Expender Base Board Rev. 0 is functional.

IEEE488_Ext_Base_Test.docx 23.07.2023 13:49 Drafted by Sven Petersen Page 2 of 2 Doc.-No.: 169-6-02-00

IEEE488_Ext_Base_Test.docx 23.07.2023 13:49 Drafted by Sven Petersen Page 1 of 1 Doc.-No.: 000-6-00-00

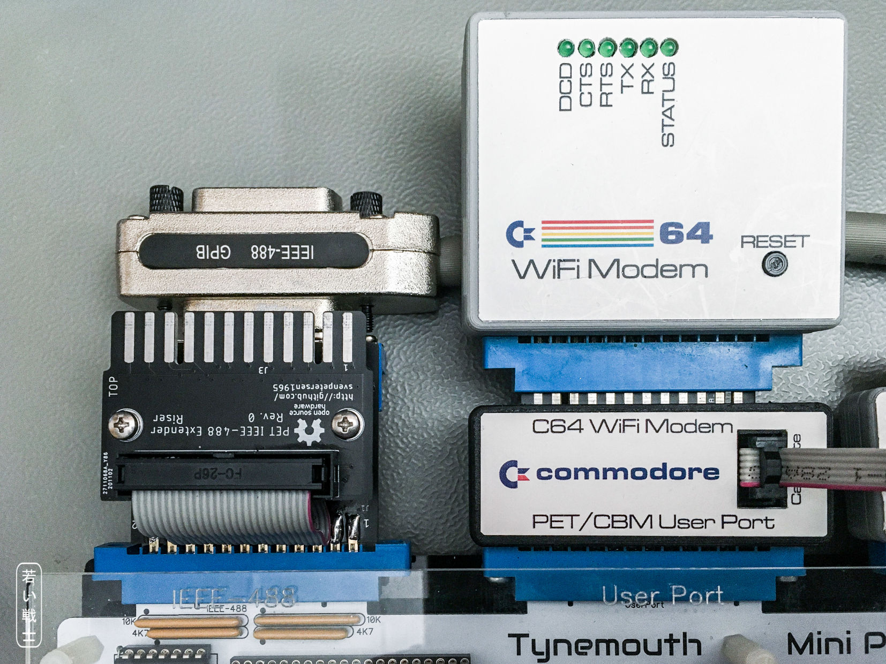
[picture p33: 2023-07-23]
Base_Centronics/Rev. 0/pictures/3369_-_Test_MiniPET.JPG

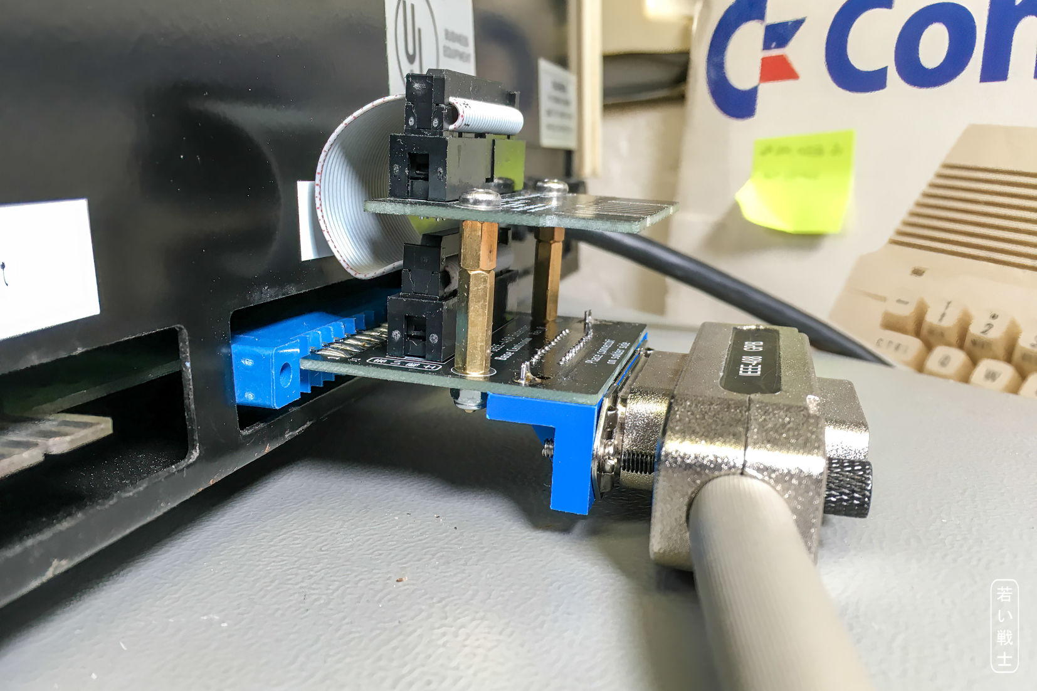
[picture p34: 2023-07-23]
Base_Centronics/Rev. 0/pictures/3052_-_Test_Fit_SD2PET.JPG

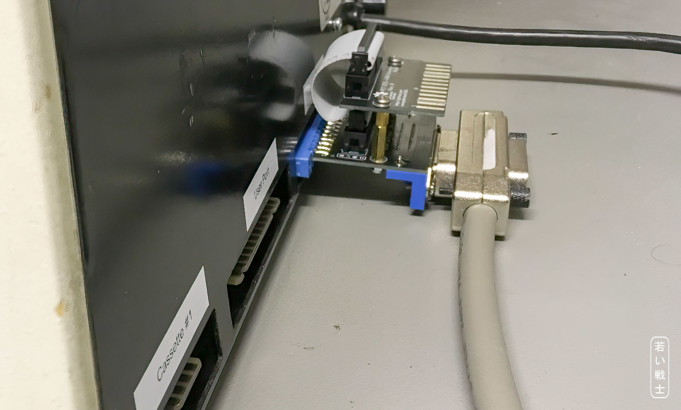
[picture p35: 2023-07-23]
Base_Centronics/Rev. 0/pictures/3016_-_Test_fit.JPG

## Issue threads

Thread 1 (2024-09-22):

How to order

FlightControl-User, 2024-09-22:
Hello!

Thank you for making this!

I own a PET8032SK and i need some way to interface with its GPIB port.
Is is possible to order from you the PET converter based board?

How can I produce/order this? What is the process?

I need to have a GPIB IEEE-488 ribbon connector that connects to the PET 8032SK GPIB port. On the other side, I just need a  MALE edge IEEE-4888 output (like on the main board already). So i can attach to it an SD2PET card ... Is it possible using the riser to have a 2nd GPIB port to extend other peripherals using GPIB?

Can you please help me?

svenpetersen1965, 2024-09-23:
So, I hope, I have understood you right... you want to connect an SD2PET to the 8032SK. The SD2PET (future) has this 2x12 edge connector and you need an adapter to the (Centronics) connector of the 8032SK.

I have already tested it with this IEEE-488 adapter:
SK IEEE port -> IEEE 488 cable (2x Centronics connector) -> adapter with riser card -> sd2pet. It works.

I think, I have both PCBs in my PCB box. Will check later today.

Regards,
Sven

FlightControl-User, 2024-10-07:
Wonderful!

Is there a way for me to easily get such an adapter and riser board somehow? I'm not really into soldering but got the equipment if I need to.

What is the easiest way for me to produce our but such an adapter?

Sven

FlightControl-User, 2024-10-07:
Maybe to make it faster, tell me your price if you can still make one for me too. :-)
I live in Belgium, so not far. If you live near Belgium, I could even drive and fetch it by car.

svenpetersen1965, 2024-10-07:
You might want to contact me by email: http://www.guitarsite.de/p4.htm

FlightControl-User, 2024-10-08:
I've sent you an email :-)

Closed 2024-10-08.

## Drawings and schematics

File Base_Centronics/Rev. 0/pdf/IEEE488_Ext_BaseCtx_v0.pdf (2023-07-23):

# Project Documentation

## Commodore IEEE-488 Extender

## Base Centronics

## Project number: 204

## Revision: 0

## Date: 18.11.2022

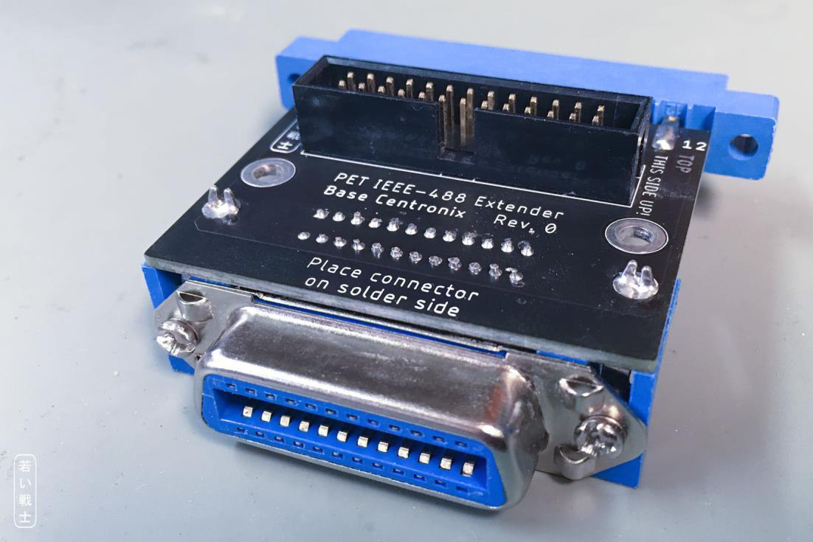
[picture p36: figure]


IEEE488_Ext_BaseCtx_ModD.docx | | 23.07.2023 17:27
Drafted by Sven Petersen | Page 1 of 4 | Doc.-No.: 204-6-01-00

### Commodore PET IEEE-488 Extender Base Centronics Rev. 0

### Module Description

The IEEE-488 extender can serve multiple purposes:

1. Splitting the card edge IEEE-488 connector via a riser board (Project No. 170), so an additional device like a SD2PET future can be connected.
2. Adapting an IEEE-488 cable to the edge connector of the PET.

Figure 1: Dimensions of the IEEE-488 Extender

## 3D-Printed Case

Depending on the intended usage, there are different sorts of 3D cases/configurations. The 3D-printed case provides a good support for the extension board and the cable. If it is only intended to use the extension as an adapter for the Centronics type (=standard) IEEE-488 cables, the top shell can be installed (J2 cannot be assembled in this case). The height above the desktop of the PET is different than that of the Tynemouth Software/TFW8bit miniPET. The miniPET adapter case is 2mm higher.

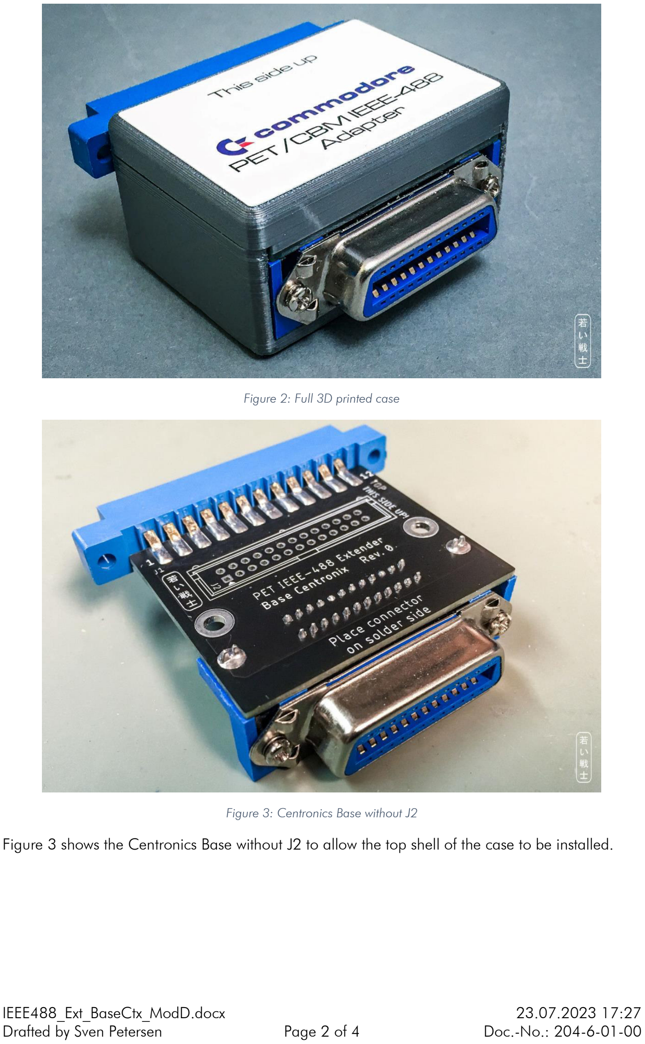
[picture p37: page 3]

IEEE488_Ext_BaseCtx_ModD.docx | | 23.07.2023 17:27
Drafted by Sven Petersen | Page 2 of 4 | Doc.-No.: 204-6-01-00

Figure 2: Full 3D printed case

Figure 3: Centronics Base without J2

Figure 3 shows the Centronics Base without J2 to allow the top shell of the case to be installed.

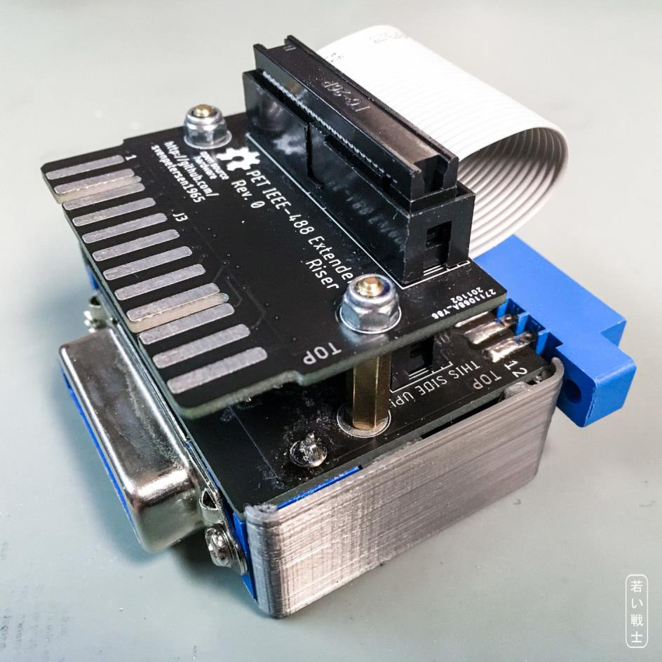
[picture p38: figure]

IEEE488_Ext_BaseCtx_ModD.docx | | 23.07.2023 17:27
Drafted by Sven Petersen | Page 3 of 4 | Doc.-No.: 204-6-01-00

Figure 4: Centronics Base with Riser and the bottom shell installed only

## Connectors

J1 is a female card edge connector, that connects to the PET/CBM Mainboard, J3 is a 24p. female Centronics connector (fits IEEE-488) (Ali Express “Series 57”), which connects to the IEEE-488 peripherals via an IEEE-488 cable. J2 is a 2x13 pin header/box connector.

J1 J3 Signal J2 | J2 Signal J3 J1
1 1 DIO1 1 | 2 DIO5 13 A
2 2 DIO2 3 | 4 DIO6 14 B
3 3 DIO3 5 | 6 DIO7 15 C
4 4 DIO4 7 | 8 DIO8 16 D
5 5 EOI 9 | 10 REN 17 E
6 6 DAV 11 | 12 GND 18 F
7 7 NRFD 13 | 14 GND 19 H
8 8 NDAC 15 | 16 GND 20 J
9 9 IFC 17 | 18 GND 21 K
10 10 SRQ 19 | 20 GND 22 L
11 11 ATN 21 | 22 GND 23 M
12 12 GND 23 | 24 GND 24 N
--GND 25 | 26 GND --
Table 1: IEEE-488 signal pinouts

IEEE488_Ext_BaseCtx_ModD.docx | | 23.07.2023 17:27
Drafted by Sven Petersen | Page 4 of 4 | Doc.-No.: 204-6-01-00

The shield of J3 is connected to GND.

## SD2PET future Splitter

The SD2PET future has an edge connector IEEE-488 interface, which does not allow to connect any other IEEE-488 peripheral. It might be desired to do so, though. In this case, the SD2PET future has to drive both, the PET and the peripheral bus load. The maximum load is not defined.

The configuration was tested with a CBM8032 and a CBM8050 floppy disk drive attached via a 1.5 meter long IEEE-488 cable. The CBM8050 has to be set (via hardware) to a device address other than 8, since this is the default address of the SD2PET future. It is not possible to switch off the CBM8050 and reconfigure the device address of the SD2PET.

Using the SD2PET future and a printer was not tested, but very likely works, since the interface circuitry is similar to the CBM8050.

The bus splitting requires the riser board, like shown in Figure 4.

## Revision History

### Rev. 0

- Prototype (fully functional)

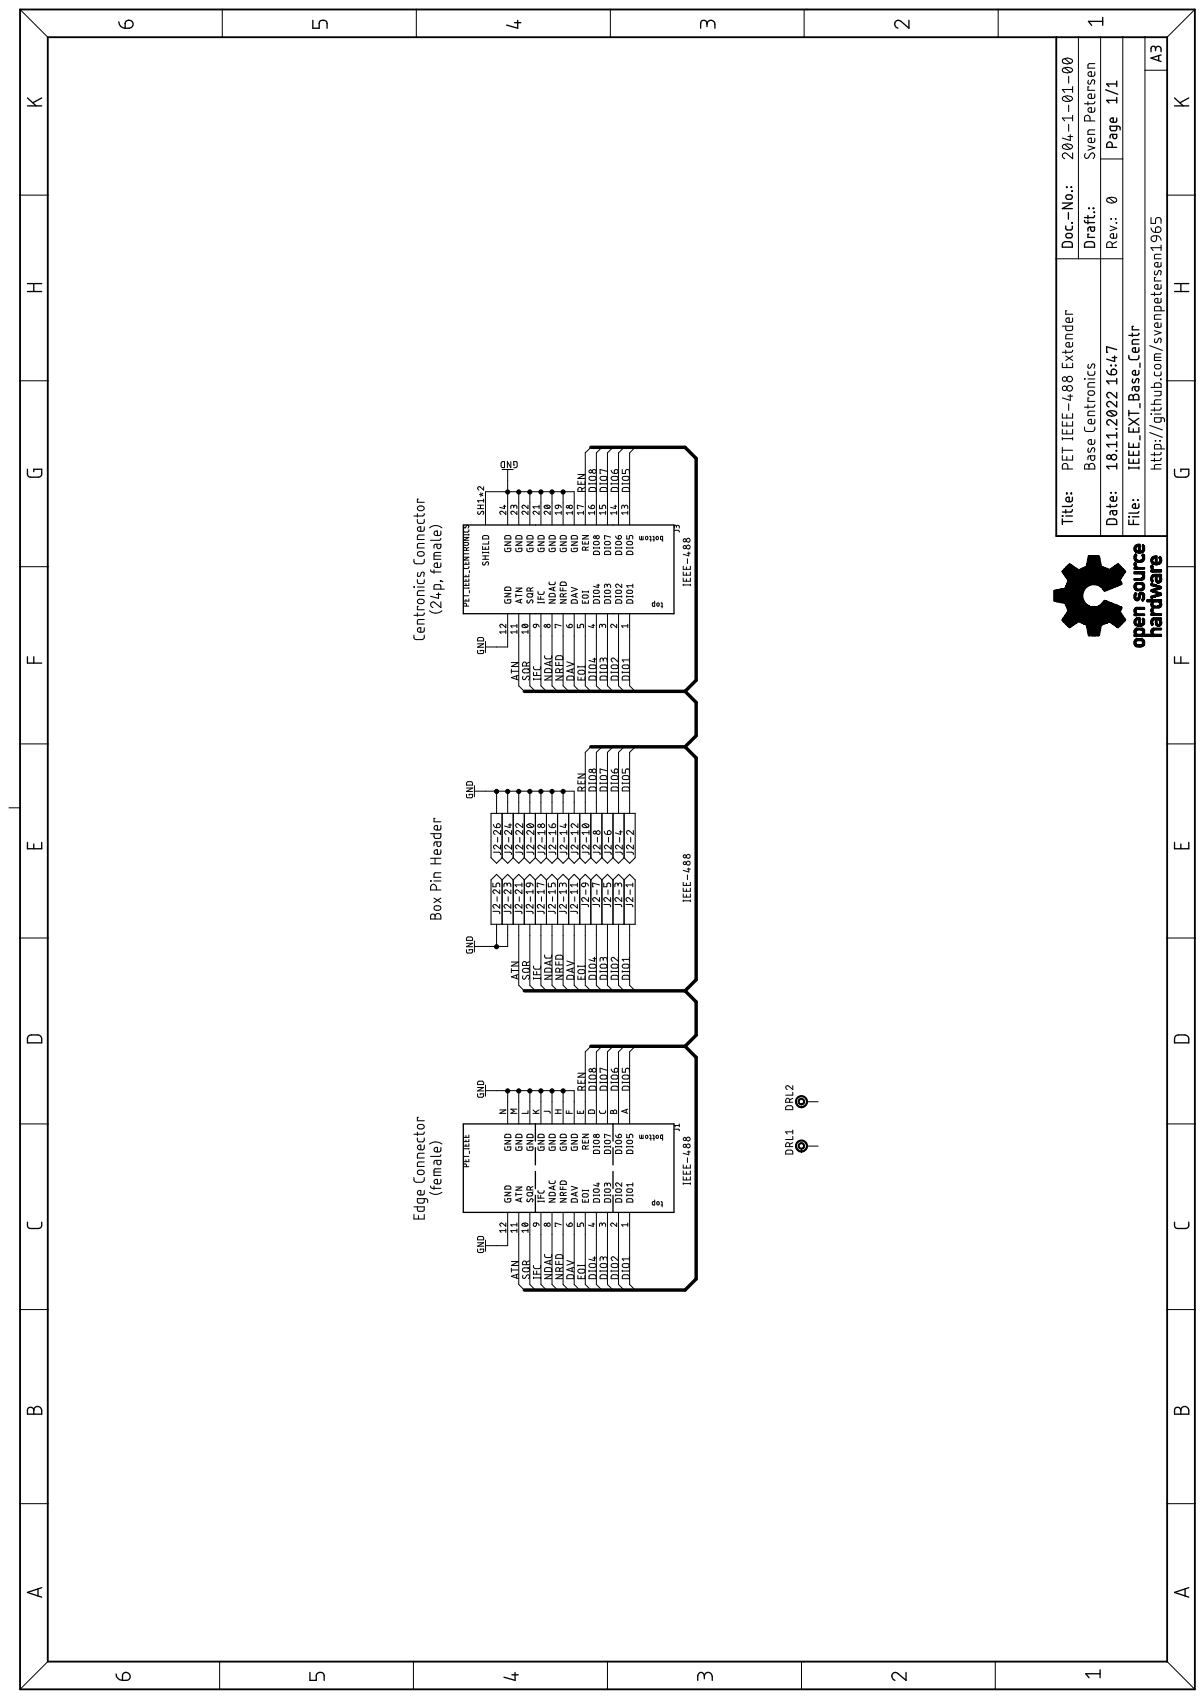
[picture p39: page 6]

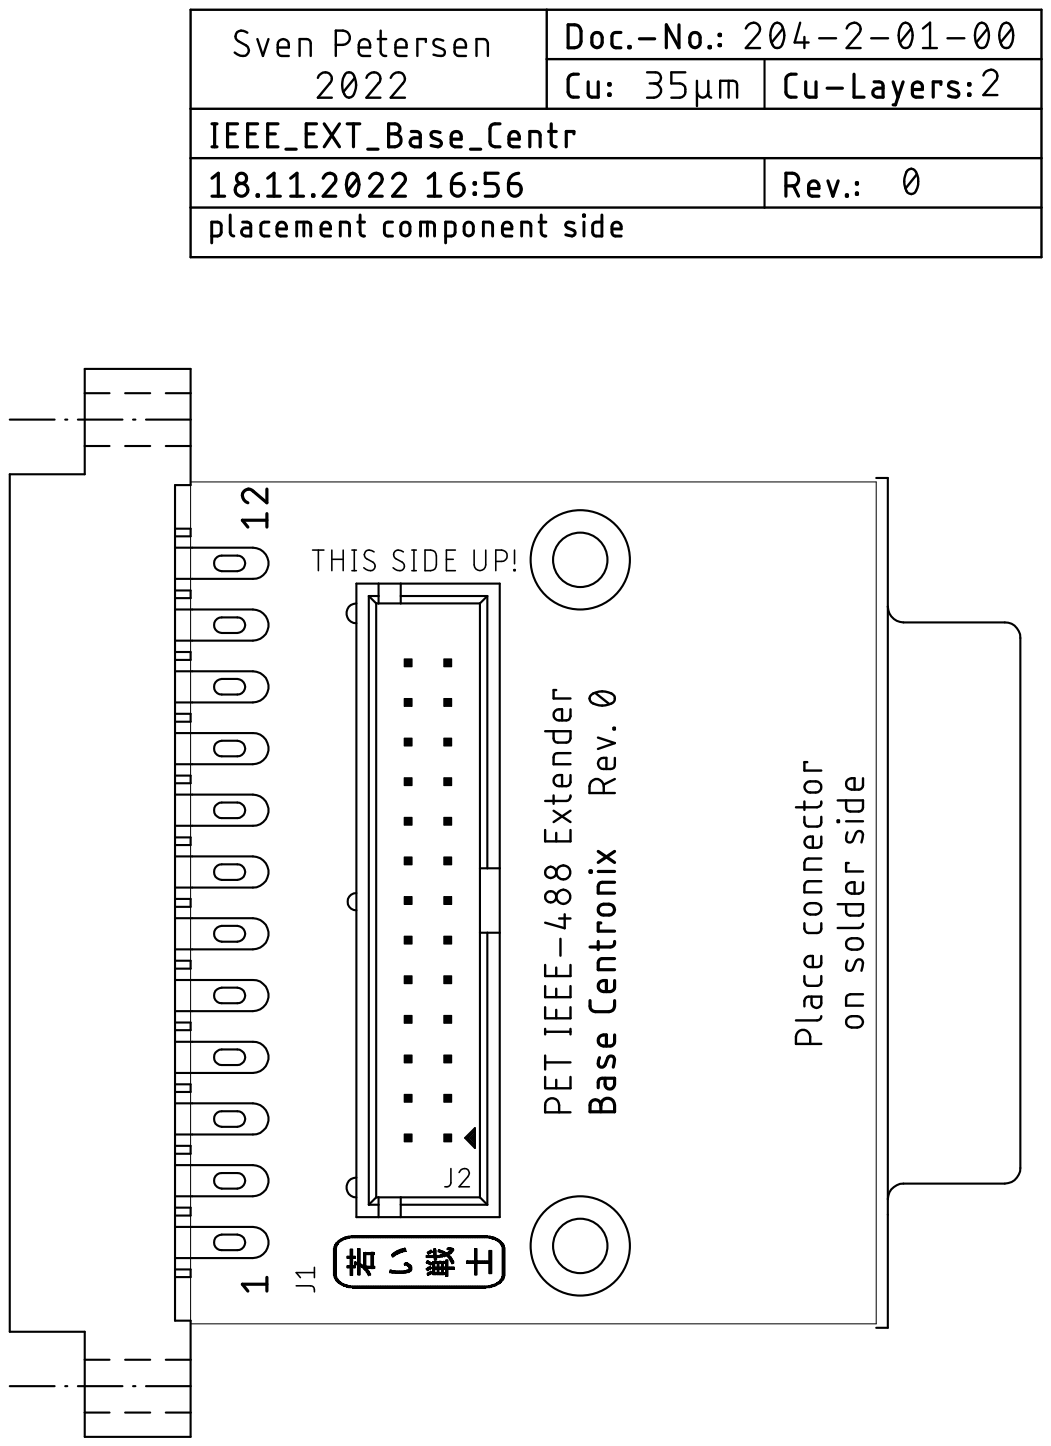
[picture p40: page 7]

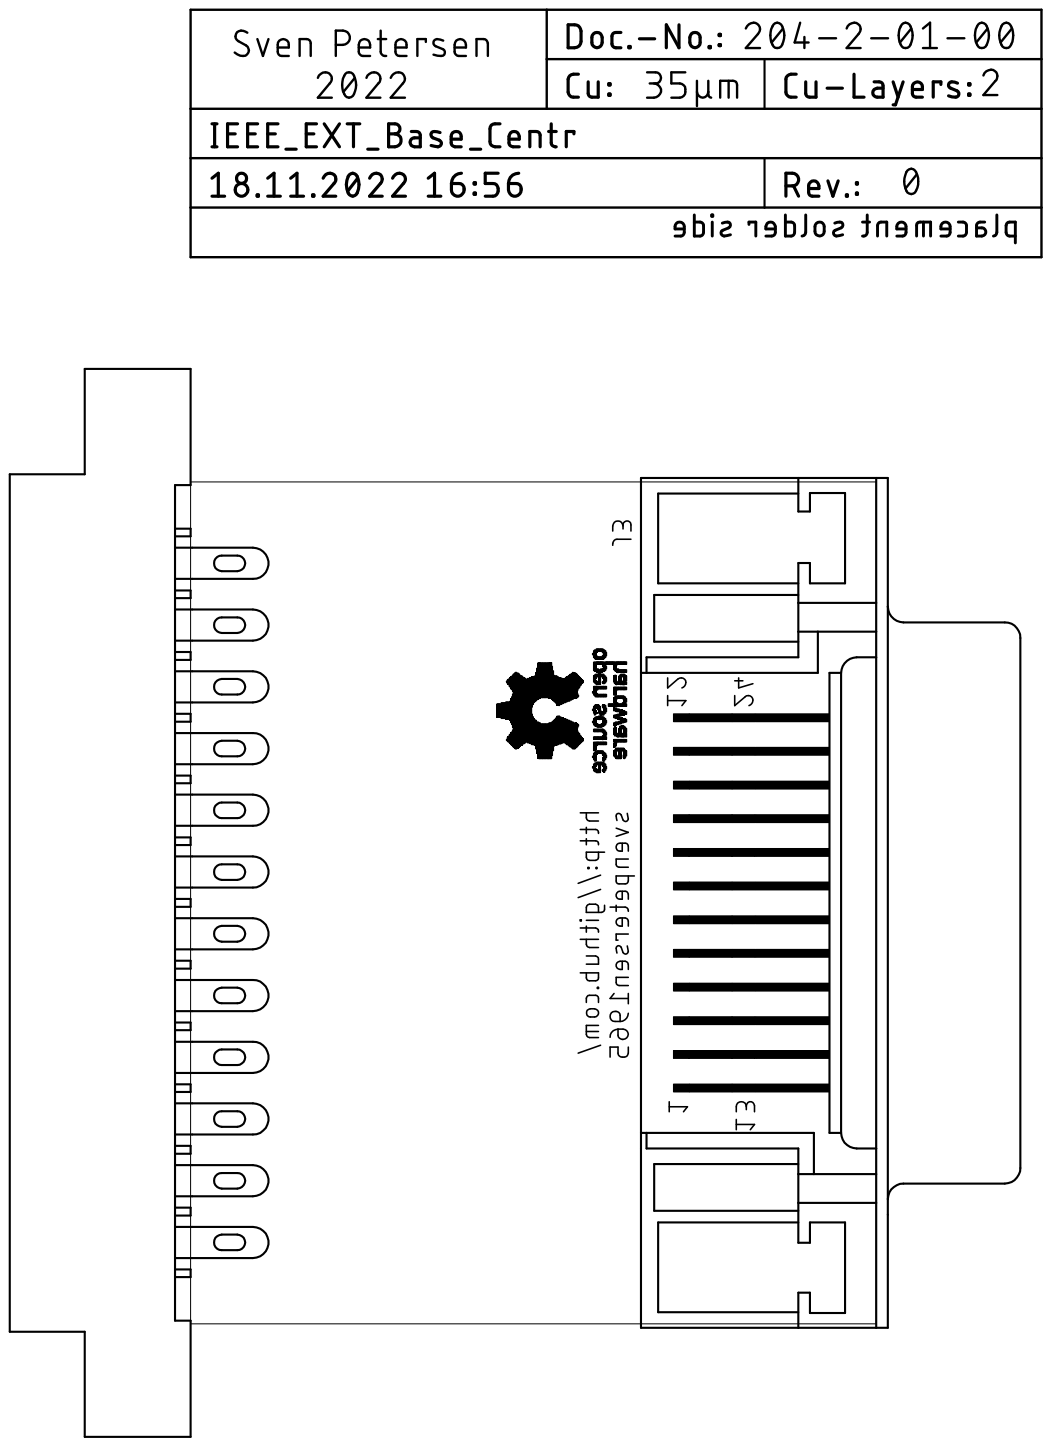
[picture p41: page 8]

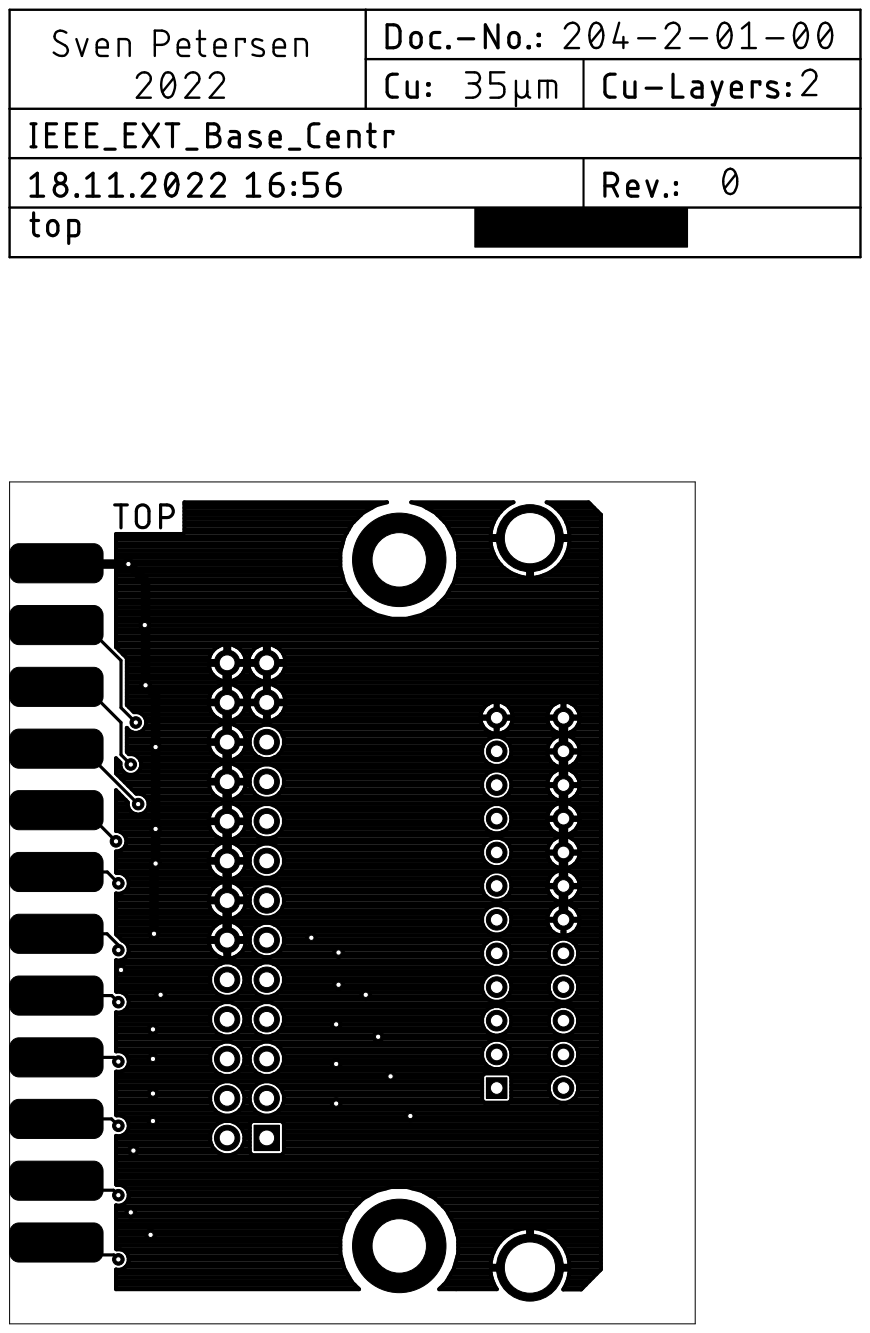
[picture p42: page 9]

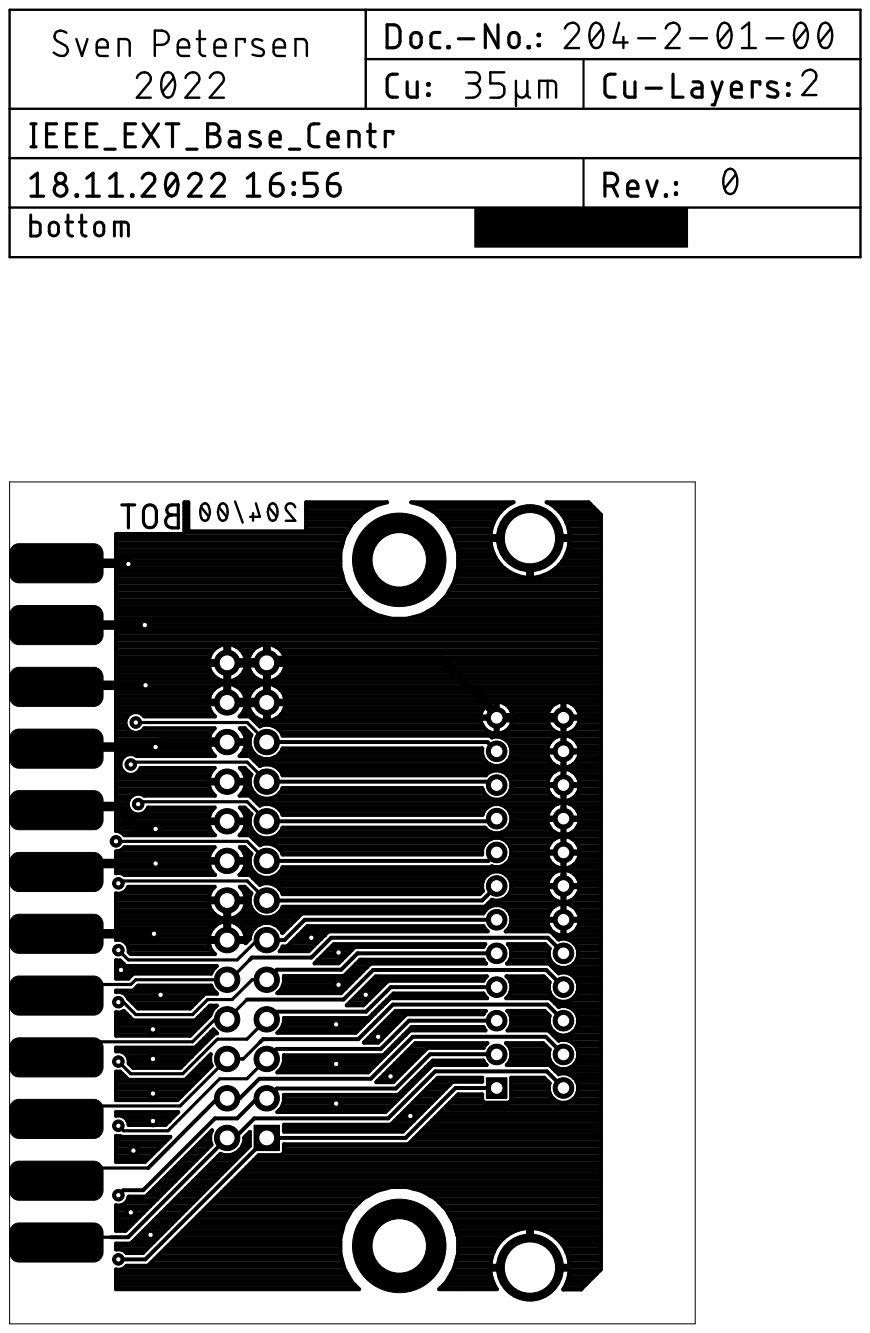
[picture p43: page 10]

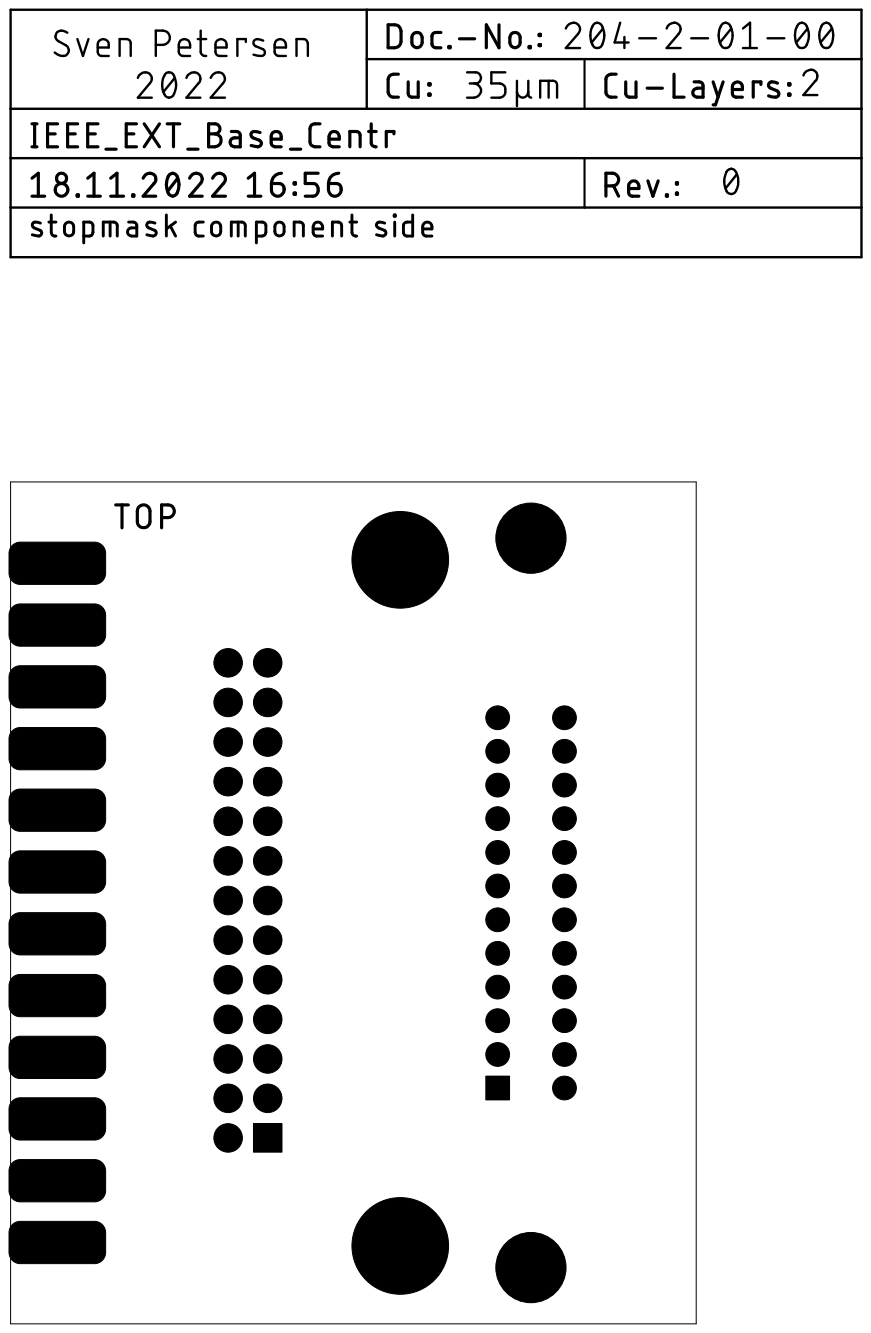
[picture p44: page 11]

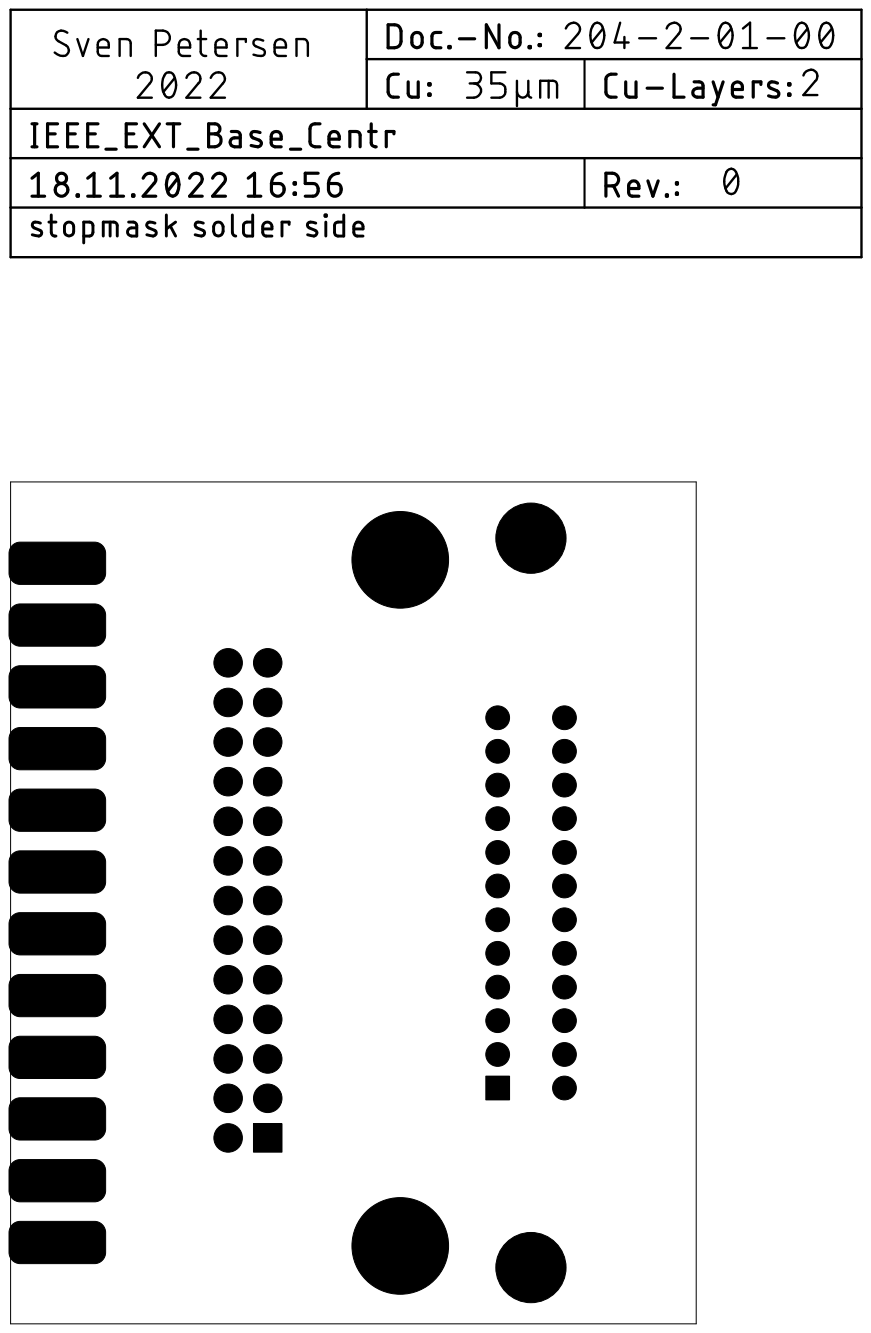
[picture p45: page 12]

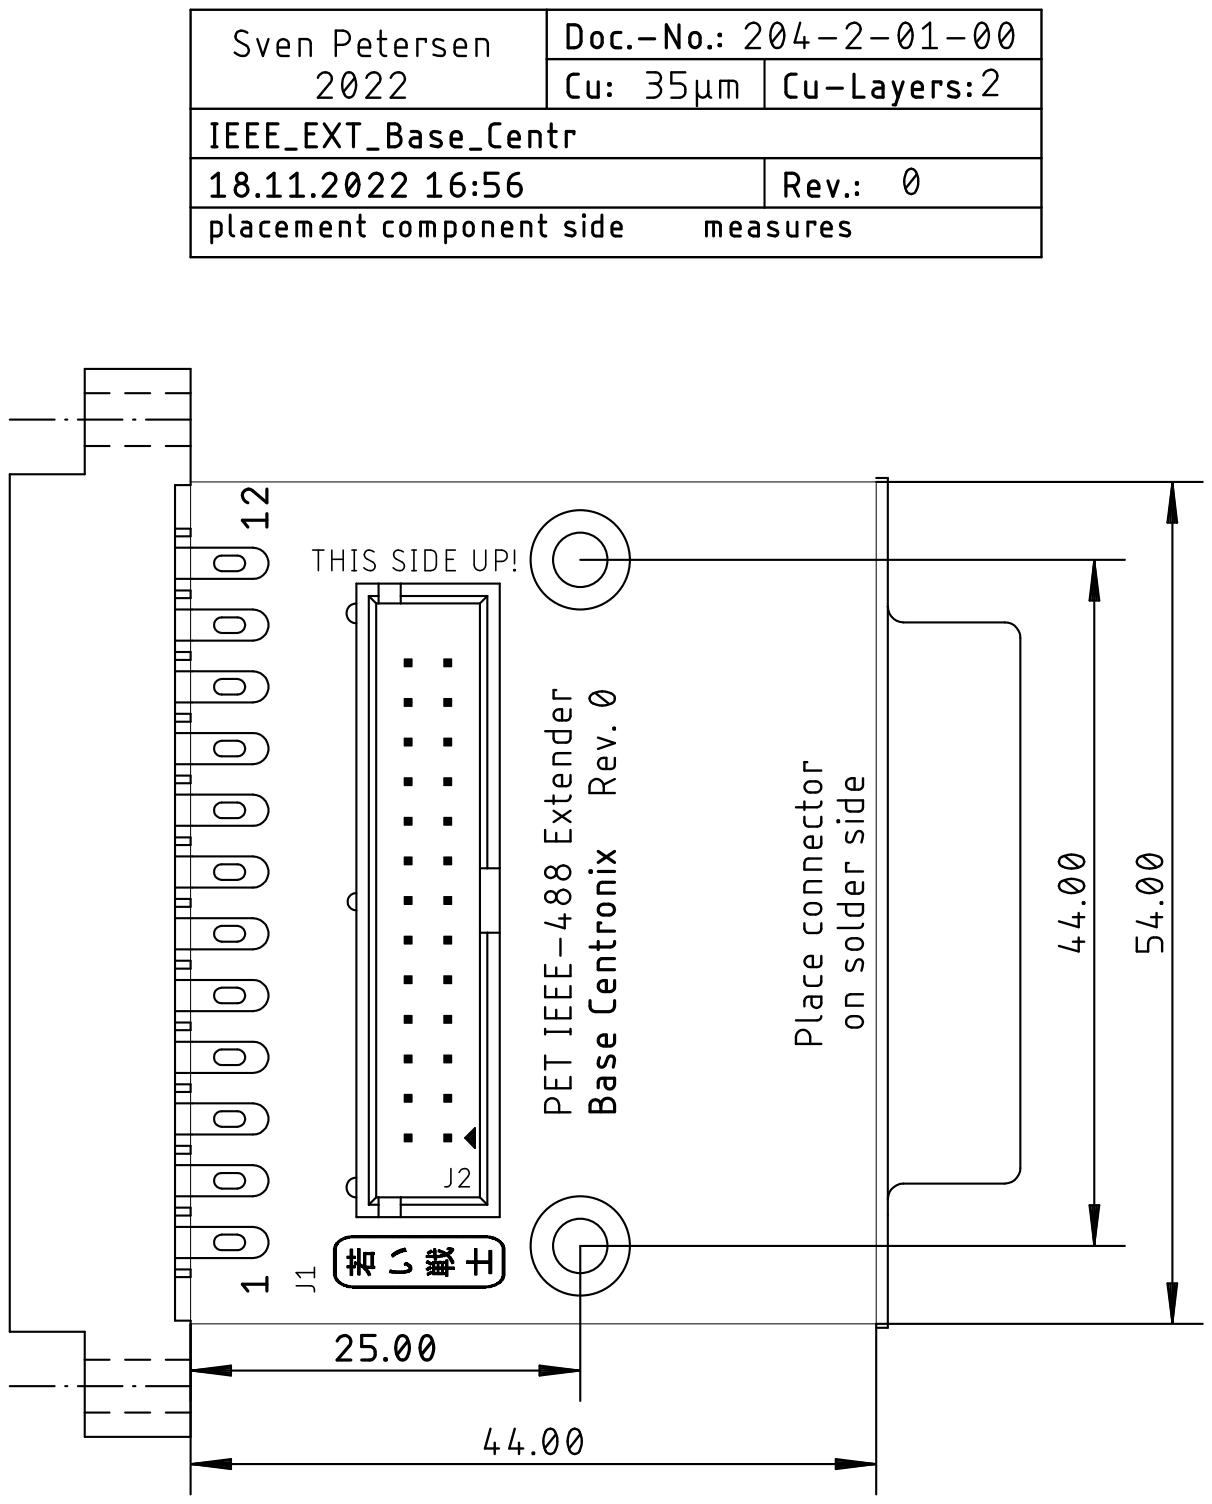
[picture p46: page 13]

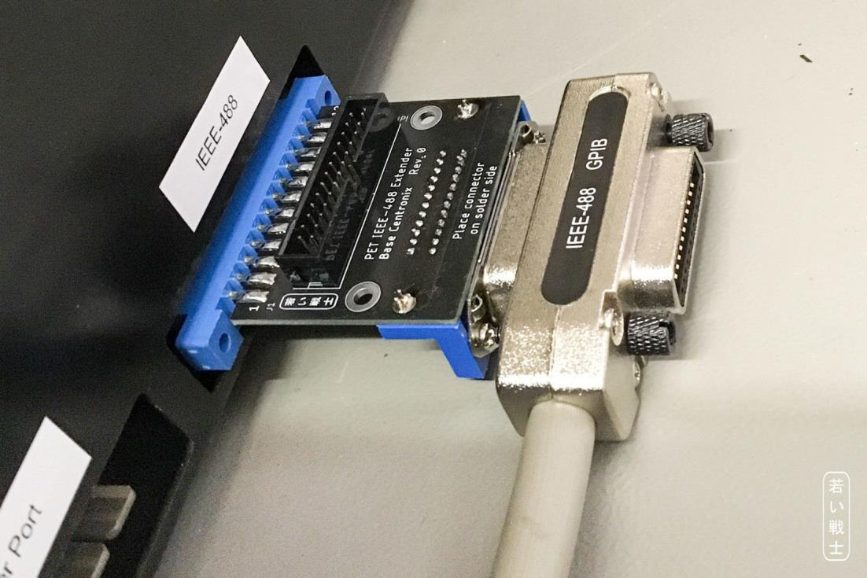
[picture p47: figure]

IEEE488_Ext_BaseCtx_Test.docx | | 23.07.2023 20:46
Drafted by Sven Petersen | Page 1 of 2 | Doc.-No.: 204-6-02-00

### Commodore PET IEEE-488 Extender Base Centronics Rev. 0

### Testing

## Setup

- CBM3016 computer
- CBM8032 computer
- CBM8050 floppy disk drive
- TFW8bit.com SD2PET future
- Standard Centronics IEEE-488 cable (1.5m)
- Centronics Base Rev. 0 with case
- Centronics Base Rev. 0 with Riser and jumper cable cable (drawing no. 169-3-02-00)
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

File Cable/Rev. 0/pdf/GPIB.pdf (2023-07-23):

Title:; Doc.-No.: 169-3-01-00; Date: 14.09.2022 13:34; GPIB.SKF; PET IEEE-488 Extender; Ribbon cable, 1.27mm, AWG28, 26p.; 24 pin Centronics, male, IDC

26-pin IDC socket with
strain relief (2.54mm pitch)
e.g. Reichelt PFL 26

(= for ribbon cable)

IEEE-488 Ribbon Cable

Draft.: Sven Petersen
File:
Rev.: 0

https://github.com/svenpetersen1965

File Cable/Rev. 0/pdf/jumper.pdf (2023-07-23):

Title:; GPIB.SKF; PET IEEE-488 Extender; Ribbon cable, 1.27mm, AWG28, 26p.; e.g. Reichelt PFL 26

26-pin IDC socket without
strain relief (2.54mm pitch)

e.g. Reichelt PFL 26

Jumper Cable to
Riser Board

Draft.: Sven Petersen
File:

Doc.-No.: 169-3-02-00 | Rev.: 0
Date: 06.01.2023 23:32 | M 1 mm = 1 mm

https://github.com/svenpetersen1965

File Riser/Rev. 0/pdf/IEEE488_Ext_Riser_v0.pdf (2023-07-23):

# Project Documentation

## Commodore PET/CBM80xx/40xx IEEE-Extender Riser

## Project number: 170

## Revision: 0

## Date: 01.11.2020

### Commodore PET IEEE-488 Extender – Riser Board Rev. 0

### Module Description


IEEE488_Ext_Riser_ModD.docx | | 18.06.2023 22:15
Drafted by Sven Petersen | Page 1 of 3 | Doc.-No.: 170-6-01-00

## Introduction

The IEEE-488 extender riser board is connected to either the base board with edge connector (Project 169) or the base board with Centronics connector (24p. = IEEE-488 connector, Project. No. 204). It serves for connecting IEEE cables with and edge connector or a peripheral like the SD2PET, which has an edge connector installed.

Figure 1: Riser Board with jumper cable and mounting material

Figure 2: Riser Board on a Centronics Base Board with an SD2PET


IEEE488_Ext_Riser_ModD.docx | | 18.06.2023 22:15
Drafted by Sven Petersen | Page 2 of 3 | Doc.-No.: 170-6-01-00

## Dimensions

Figure 3: Dimensions of the IEEE-488 Extender

## Connectors

J3/top Signal J2 | J2 Signal J3/bottom
1 DIO1 1 | 2 DIO5 A
2 DIO2 3 | 4 DIO6 B
3 DIO3 5 | 6 DIO7 C
4 DIO4 7 | 8 DIO8 D
5 EOI 9 | 10 REN E
6 DAV 11 | 12 GND F
7 NRFD 13 | 14 GND H
8 NDAC 15 | 16 GND J
9 IFC 17 | 18 GND K
10 SRQ 19 | 20 GND L
11 ATN 21 | 22 GND M
12 GND 23 | 24 GND N
-GND 25 | 26 GND -
Table 1: IEEE-488 signal pinouts

J3 is a card edge structure on the PCB, which connects to the IEEE-488 peripherals via the PET-IEEE-488 cable or directly (in case of the SD2PET future). J2 is a 2x13 pin header/box connector for the jumper cable to the respective base board.

## Cable

The jumper ribbon cable connects J2 or the Riser Board to J2 of the desired base board. Since this cable is usually installed only once, there is no need for a strain relief. This way, the standoff between riser board and the base board can be 15mm only.


IEEE488_Ext_Riser_ModD.docx | | 18.06.2023 22:15
Drafted by Sven Petersen | Page 3 of 3 | Doc.-No.: 170-6-01-00

## 3D-Printed Case

The bottom Shell of the Case for the Centronics Base can be used to support the board stack.

Figure 4: Board stack with Centronics Base and the bottom shell of the Centronics case

The recommended mounting material:

- 2x 15mm standoffs
- 2x M3x8 Screws (e.g. DIN 7985, Philips dead)
- 2x Nut M3 self-locking (DIN 985)

## Application Note

When using it as a splitter for the SD2PET, it is not tested to drive more than the SD2PET and one more peripheral. It is suspected, that the SD2PET is not capable to drive bussed with several devices.

## Revision History

### Rev. 0

- Prototype (fully functional)








Rev.: 0; 1 File:; Title:; Doc.-No.: 169-3-02-00; Date: 06.01.2023 23:32; GPIB.SKF; PET IEEE-488; Extender; Riser Board; Ribbon cable, 1.27mm,; AWG28, 26p.; e.g. Reichelt PFL 26

Draft.: Sven Petersen

Jumper Cable to

https://github.com/svenpetersen1965

26-pin IDC socket without

strain relief (2.54mm pitch)

1 Box pin header, 2x13p,; 2X13WV J2 e.g. Reichelt.de WSL 26G; 2 IDC receptacle, 2x13p,; 60mm AWG28, 26p, pitch; 2 standoff M3/15mm (male; +female); 2 locking nuts M3 DIN985, zinc plated

Pos. Qty Value Footprint Ref.-No. Comment

1 1 170-2-01-00 2 Layer PCB Rev. 0 2 layer, Cu 35µ, HASL, 38.0mm x 54.0mm, 1.6mm FR4

Cable (Drawing 169-2-03-00) e.g. Reichelt.de PFL 26 (do not install strain relief)

Cable (Drawing 169-2-03-00) ribbon cable e.g. Reichelt.de AWG 28-26G 3M (3 meters)

### 2 Screws, M3x8 DIN7985, philips head, zinc plated

## PET IEEE-488 Extender - Riser Board Rev. 0

## Bill of Material Rev. 0.0

IEEE488_Riser_BOM_v0_0.xlsx

Drafted by Sven Petersen Page 1 of 1

18.06.2023 22:12
Doc.No.: 170-5-01-00.0

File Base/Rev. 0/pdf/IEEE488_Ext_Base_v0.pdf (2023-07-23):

# Project Documentation

## Commodore IEEE-488 Extender Base

## Project number: 169

## Revision: 0

## Date: 03.09.2022



IEEE488_Ext_Base_ModD.docx | | 23.07.2023 15:42
Drafted by Sven Petersen | Page 1 of 3 | Doc.-No.: 169-6-01-00

### Commodore PET IEEE-488 Extender Base Board Rev. 0

### Module Description

The IEEE-488 extender can serve multiple purposes:

1. Splitting the card edge IEEE-488 connector, so an additional device other than a SD2PET future can be connected.
2. Connecting a cheap DIY ribbon IEEE-488 cable. It is recommended to keep this ribbon cable as short as possible

Figure 1: Dimensions of the IEEE-488 Extender

## Connectors

J1 is a female card edge connector, that connects to the PET/CBM Mainboard, J3 is a card edge structure on the PCB, which connects to the IEEE-488 peripherals via the PET-IEEE-488 cable or directly (in case of the SD2PET future). J2 is a 2x13 pin header/box connector.


IEEE488_Ext_Base_ModD.docx | | 23.07.2023 15:42
Drafted by Sven Petersen | Page 2 of 3 | Doc.-No.: 169-6-01-00
J1, J3/top Signal J2 | J2 Signal J1, J3/bottom
1 DIO1 1 | 2 DIO5 A
2 DIO2 3 | 4 DIO6 B
3 DIO3 5 | 6 DIO7 C
4 DIO4 7 | 8 DIO8 D
5 EOI 9 | 10 REN E
6 DAV 11 | 12 GND F
7 NRFD 13 | 14 GND H
8 NDAC 15 | 16 GND J
9 IFC 17 | 18 GND K
10 SRQ 19 | 20 GND L
11 ATN 21 | 22 GND M
12 GND 23 | 24 GND N
-GND 25 | 26 GND -
Table 1: IEEE-488 signal pinouts

## Pictures

Figure 2: IEEE-488 Extender Base Board


IEEE488_Ext_Base_ModD.docx | | 23.07.2023 15:42
Drafted by Sven Petersen | Page 3 of 3 | Doc.-No.: 169-6-01-00

Figure 3: Base Board with SD2PET Future and a ribbon cable

## Revision History

### Rev. 0

- Prototype (fully functional)









IEEE488_Ext_Base_Test.docx | | 23.07.2023 13:49
Drafted by Sven Petersen | Page 1 of 2 | Doc.-No.: 169-6-02-00

### Commodore PET IEEE-488 Extender Base Board Rev. 0

### Testing

## Setup

The tests were conducted with a CBM8032 computer, a CBM8050 Floppy Disk Drive, an SD2PET future and a DIY ribbon cable (appr. 1 meter long). Further, a C64 with an IEEE-488 interface was used

## Test Execution

### Direct SD2PET

The SD2PET future was connected to the Base Board, which was then connected to the IEEE-488 port of the CBM8032.

The SD2PET could be accessed without a problem.

### CBM8050 via ribbon cable

The CBM8050 was connected via the base board and the ribbon cable. The 8050 could be accessed.

### CBM8050 via ribbon cable to IEEE488 interface and a C64

Figure 1: Test with C64 an IEEE-488 interface and a CBM8050

The CBM8050 could be accessed via the shown configuration. The result was not perfect, though. It is not determined, if this is matter of the interface or the ribbon cable.

IEEE488_Ext_Base_Test.docx | | 23.07.2023 13:49
Drafted by Sven Petersen | Page 2 of 2 | Doc.-No.: 169-6-02-00

## Conclusion

The PET IEEE-488 Expender Base Board Rev. 0 is functional.

Pos. Qty Value Footprint Ref.-No. Comment

1 1 169-2-01-00 2 Layer PCB Rev. 0 2 layer, Cu 35µ, HASL, 48.0mm x 54.0mm, 1.6mm FR4

1 2x13 box pin header,

2.54mm

2X13WV J2 e.g. Reichelt.de WSL26G

1 2x12 edge connector

3.96mm pitch

USERPORT J1 edge connector, C64 user port, Ali Express: "Series 805"

## Commodore PET IEEE-488 Extender Base Board Rev. 0

## Bill of Material Rev. 0.0

IEEEBase_BOM_v0_0.xlsx

Drafted by Sven Petersen Page 1 of 1

23.07.2023 15:38
Doc.No.: 169-5-01-00.0

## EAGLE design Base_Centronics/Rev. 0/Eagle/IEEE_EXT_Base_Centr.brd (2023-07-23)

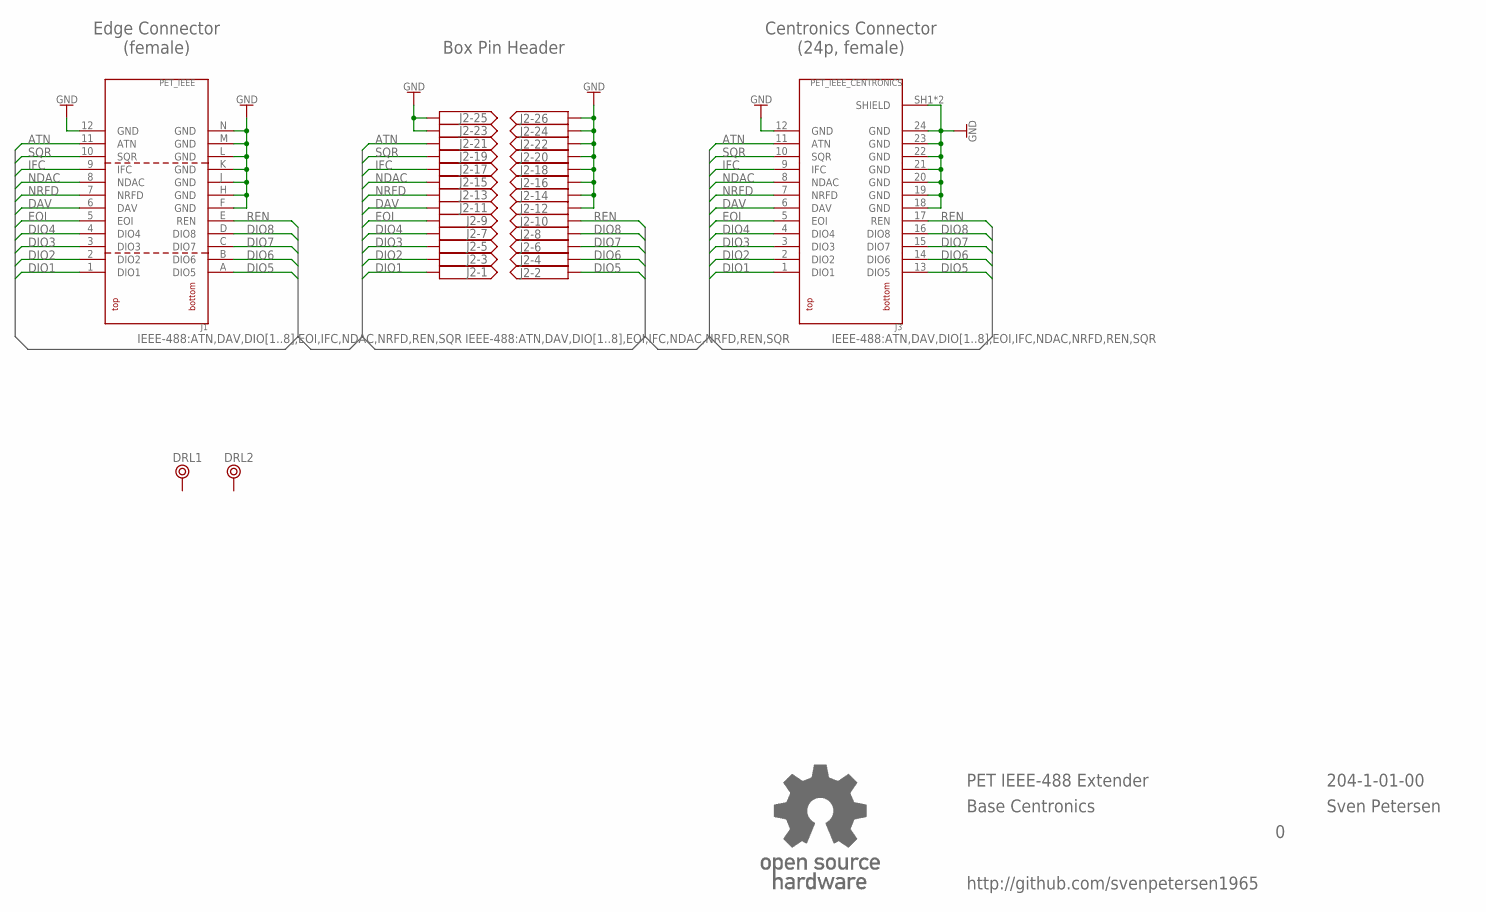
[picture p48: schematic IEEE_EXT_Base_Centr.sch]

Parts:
DRL1, DRL2: BOHR3,5
J1: PET_IEEE; USERPORT
J2: 2X13WANNE; 2X13WV
J3: PET_IEEE_CENTRONICS; CENTRONICS24
U$9: OPEN_SOURCE_HW; OPENHW

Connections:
ATN: J1.11 (ATN), J2.21, J3.11 (ATN)
DAV: J1.6 (DAV), J2.11, J3.6 (DAV)
DIO1: J1.1 (DIO1), J2.1, J3.1 (DIO1)
DIO2: J1.2 (DIO2), J2.3, J3.2 (DIO2)
DIO3: J1.3 (DIO3), J2.5, J3.3 (DIO3)
DIO4: J1.4 (DIO4), J2.7, J3.4 (DIO4)
DIO5: J1.A (DIO5), J2.2, J3.13 (DIO5)
DIO6: J1.B (DIO6), J2.4, J3.14 (DIO6)
DIO7: J1.C (DIO7), J2.6, J3.15 (DIO7)
DIO8: J1.D (DIO8), J2.8, J3.16 (DIO8)
EOI: J1.5 (EOI), J2.9, J3.5 (EOI)
GND: J1.12 (GND), J1.F (GND), J1.H (GND), J1.J (GND), J1.K (GND), J1.L (GND), J1.M (GND), J1.N (GND), J2.12, J2.14, J2.16, J2.18, J2.20, J2.22, J2.23, J2.24, J2.25, J2.26, J3.12 (GND), J3.18 (GND), J3.19 (GND), J3.20 (GND), J3.21 (GND), J3.22 (GND), J3.23 (GND), J3.24 (GND), J3.SH1 (SHIELD), J3.SH2 (SHIELD)
IFC: J1.9 (IFC), J2.17, J3.9 (IFC)
NDAC: J1.8 (NDAC), J2.15, J3.8 (NDAC)
NRFD: J1.7 (NRFD), J2.13, J3.7 (NRFD)
REN: J1.E (REN), J2.10, J3.17 (REN)
SQR: J1.10 (SQR), J2.19, J3.10 (SQR)

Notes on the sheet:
PET IEEE-488 Extender
204-1-01-00
Sven Petersen
http://github.com/svenpetersen1965
Base Centronics
Edge Connector (female)
Centronics Connector (24p, female)
Box Pin Header

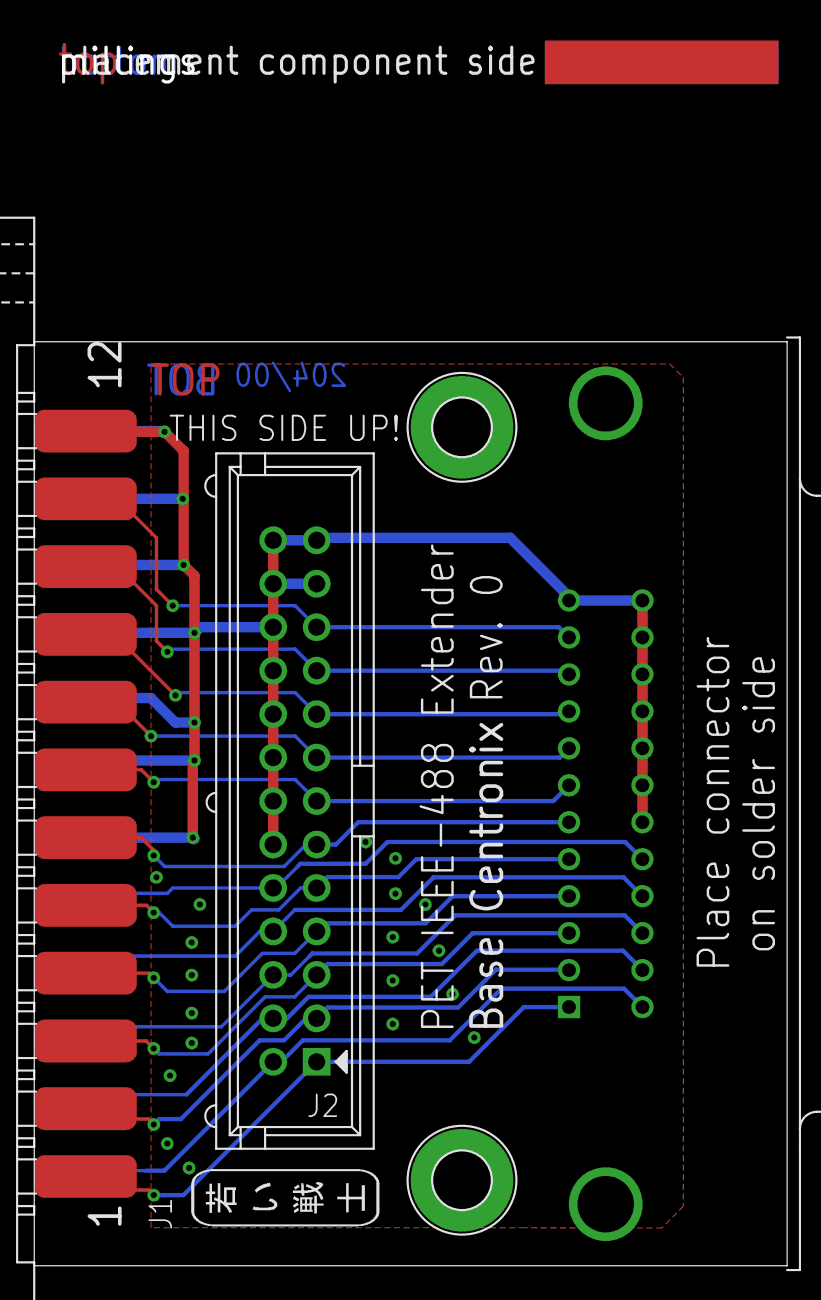
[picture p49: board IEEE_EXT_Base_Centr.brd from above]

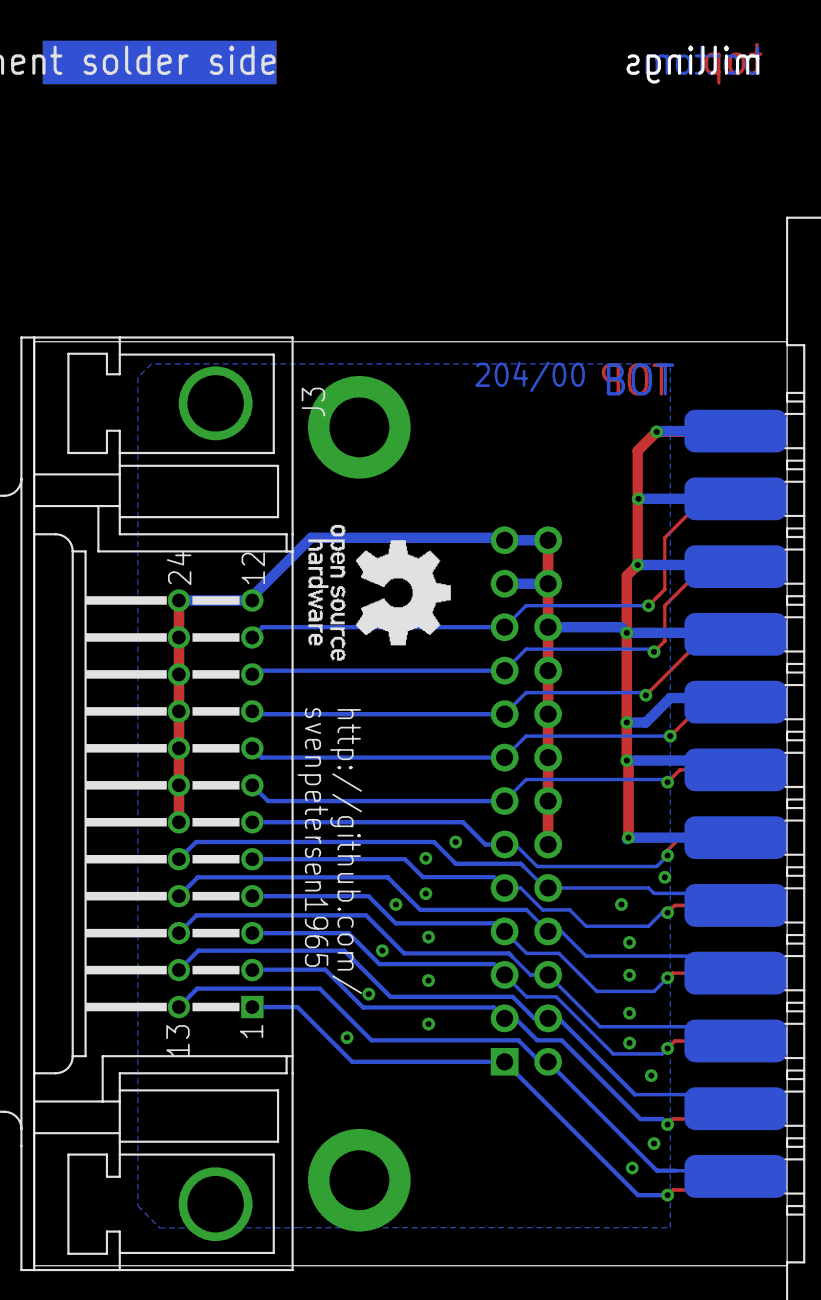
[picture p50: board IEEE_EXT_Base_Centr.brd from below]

Board: 2 copper layers, 44.0 x 54.0 mm, 9 parts (2 on the bottom side), 17 nets.

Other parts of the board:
U$8: PCB-TITLE/
U$10: 2LAYER
U$11: SVEN_TAG

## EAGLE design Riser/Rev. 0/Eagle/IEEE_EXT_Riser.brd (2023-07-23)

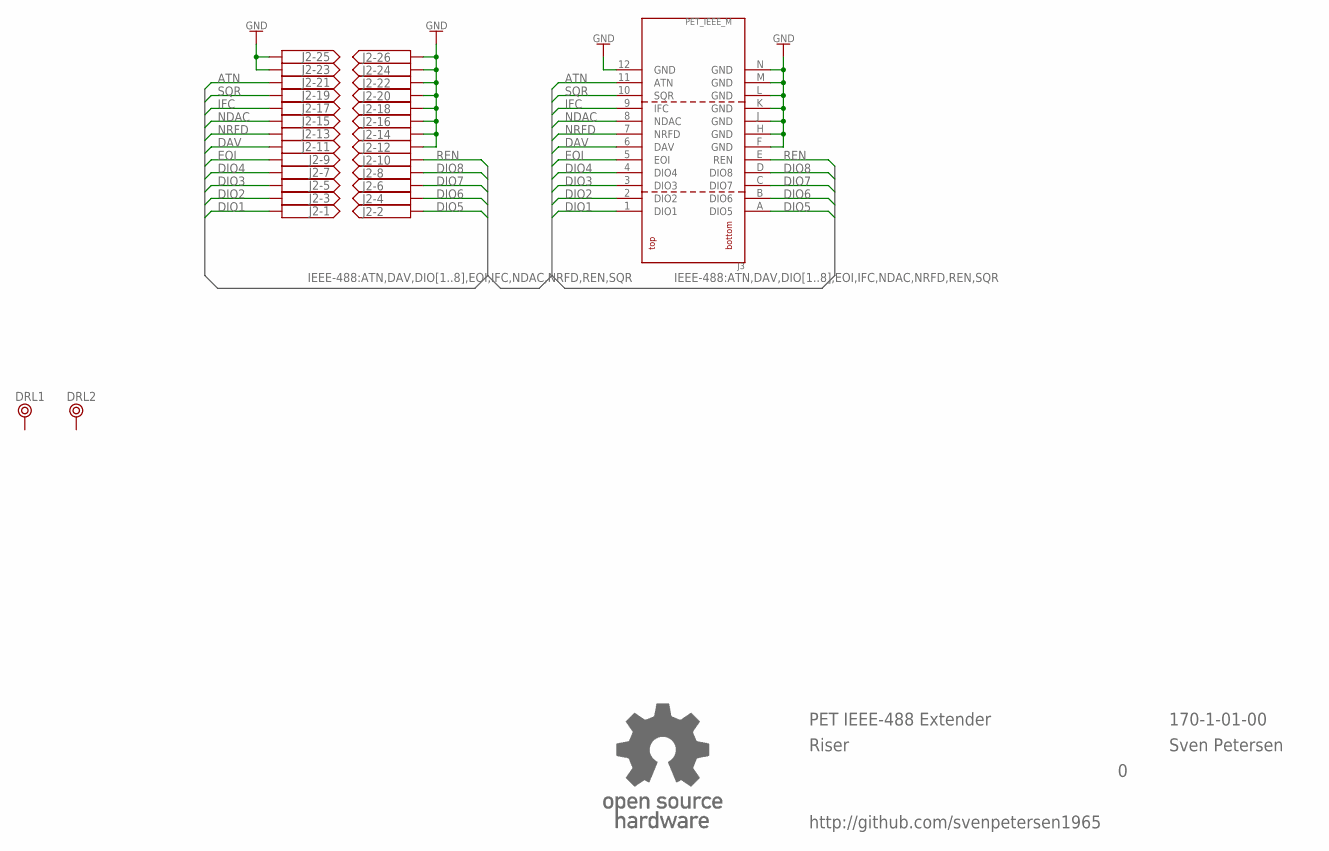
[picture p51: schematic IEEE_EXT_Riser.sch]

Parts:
DRL1, DRL2: BOHR3,5
J2: 2X13WANNE; 2X13WV
J3: PET_IEEE_M
U$9: OPEN_SOURCE_HW; OPENHW

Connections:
ATN: J2.21, J3.11 (ATN)
DAV: J2.11, J3.6 (DAV)
DIO1: J2.1, J3.1 (DIO1)
DIO2: J2.3, J3.2 (DIO2)
DIO3: J2.5, J3.3 (DIO3)
DIO4: J2.7, J3.4 (DIO4)
DIO5: J2.2, J3.A (DIO5)
DIO6: J2.4, J3.B (DIO6)
DIO7: J2.6, J3.C (DIO7)
DIO8: J2.8, J3.D (DIO8)
EOI: J2.9, J3.5 (EOI)
GND: J2.12, J2.14, J2.16, J2.18, J2.20, J2.22, J2.23, J2.24, J2.25, J2.26, J3.12 (GND), J3.F (GND), J3.H (GND), J3.J (GND), J3.K (GND), J3.L (GND), J3.M (GND), J3.N (GND)
IFC: J2.17, J3.9 (IFC)
NDAC: J2.15, J3.8 (NDAC)
NRFD: J2.13, J3.7 (NRFD)
REN: J2.10, J3.E (REN)
SQR: J2.19, J3.10 (SQR)

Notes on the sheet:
PET IEEE-488 Extender
170-1-01-00
Sven Petersen
http://github.com/svenpetersen1965
Riser

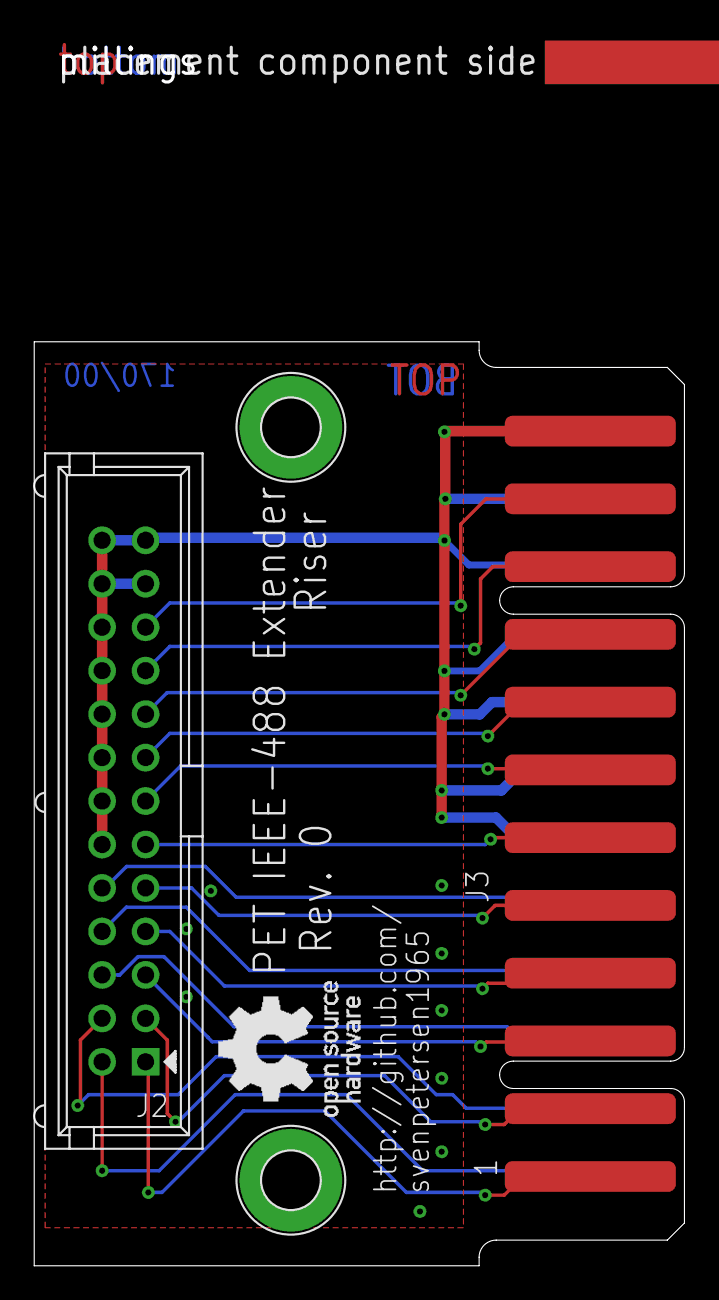
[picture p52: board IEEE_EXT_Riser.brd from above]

Board: 2 copper layers, 38.0 x 54.0 mm, 7 parts (0 on the bottom side), 17 nets.

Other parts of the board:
U$8: PCB-TITLE/
U$10: 2LAYER
